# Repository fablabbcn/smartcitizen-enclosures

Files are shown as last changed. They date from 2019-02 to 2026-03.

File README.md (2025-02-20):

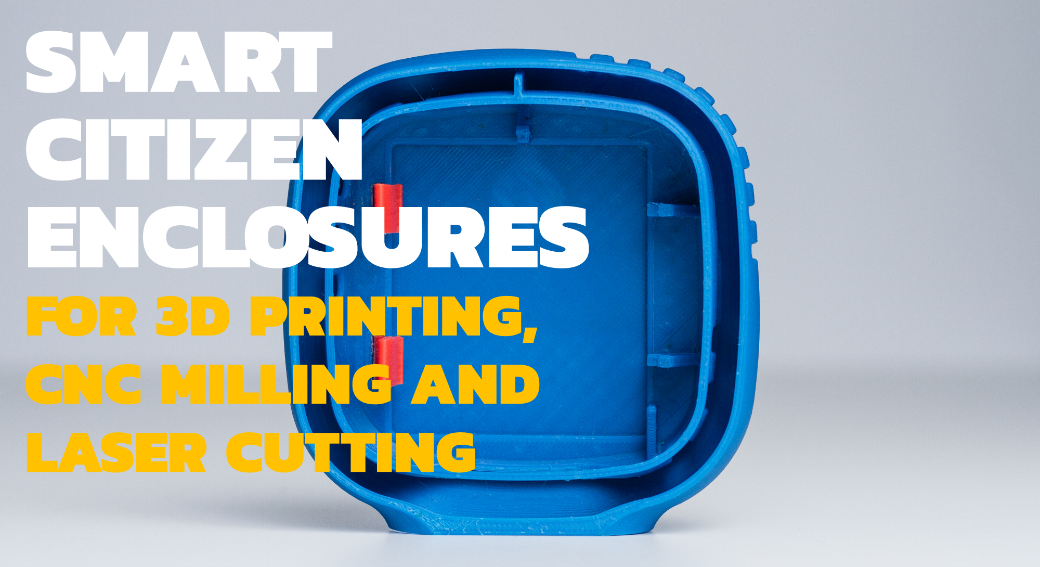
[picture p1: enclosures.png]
Smart Citizen Cases


Smart Citizen Enclosures
========================



This is a repository we host enclosures we are developing for the Smart Citizen Kit 1.5 and 2.X family. If you are looking for outdoor cases for the _SmartCitizen Kit or Stations_, make sure to visit the [variants table](/Air/) to find out what best suits your needs. If you are looking for _Water Kits or Stations_, check this [table](/Water/)

### Warning

Please, beware that this is always a _work in progress archive_. Sometimes documentation might be missing. Open an [issue](https://github.com/fablabbcn/smartcitizen-enclosures/issues) if you need!

### Contribute

* [Download](https://github.com/fablabbcn/smartcitizen-enclosures/archive/master.zip) and 3D print the files.
* Ask questions on [Issues](https://github.com/fablabbcn/smartcitizen-enclosures/issues).
* Share your changes using [Pull Requests](https://github.com/fablabbcn/smartcitizen-enclosures/pulls).
* Show and discuss your designs in the [forum](https:forum.smartcitizen.me).

### License

<br />This work is licensed under a <a rel="license" href="http://creativecommons.org/licenses/by-nc-sa/4.0/">Creative Commons Attribution-NonCommercial-ShareAlike 4.0 International License</a>.

### Credits

* Content under folder `SmartCitizen Case V1.5.1` has received funding from the European Union's Horizon 2020 research and innovation program under the grant agreement No. [688620](https://cordis.europa.eu/project/rcn/199877/factsheet/en)

* Content under folder the other folders has received funding from the European Union's Horizon 2020 research and innovation program under the grant agreement No. [689954](https://cordis.europa.eu/project/rcn/202639/factsheet/en)

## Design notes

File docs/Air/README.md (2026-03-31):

# Air Quality enclosures

These are examples of some outdoor cases for the different versions of the SCK with other sensors. You will find full 3D printed solutions, or some more complex solutions to be milled in a CNC on plastic.

!!! info "How to contribute?"
    You can download the files and make them. If you edit them or want to contribute, you can upload them to this repository with a [Pull Request!](https://github.com/fablabbcn/smartcitizen-enclosures/pull/new/master).

We give some recommendations for each enclosure's fabrication process in each design's folder. 

!!! warning "No enclosure is perfect"
    Keep in mind that no enclosure is perfect and that it will not compensate fully sun radiation and/or humidity extremes. All the enclosures in this folder have been tested, but keep in mind that outdoor conditions can be unpredictable.

## Variants

The table below will guide you through the selection process of your enclosure:

{{ insert_cards(card_type="unit", filter="page_type", value="version_index") }}

### Community contributed enclosures

|ID		|Sensors					|Exposure				|Extras		|Process		|Files 																														|
|:-:	|:-:						|:-:					|:-:		|:-:			|:-: 																															|
|	[Prius1954](https://github.com/Prius1954) |SCK2.1 + PMS50003			|-						|-			|3D Printing	|[Files](/Air/SCK2.1/SCK2.1_PMS5003/3D Printed SCK2.1 IaaC Style)												|
|	[Viadukaduk](https://lawaai.viadukaduk.be/)	|SCK2.1 + PMS50003			|OUTDOOR				|-			|3D Printing	|[Files](/Air/SCK2.1/SCK2.1_PMS5003/3D Printed Modular Viadukaduk/)													|
|		| SCK2.1 + PMS50003			|OUTDOOR				|-			|3D Printing	|[Files](/Air/SCK2.1/SCK2.1_PMS5003/3D Printed Prototype/)															|
| [serialc](https://www.printables.com/es/@serialc_251995) |SCK2.1 + PMS5003 + GPS 	|OUTDOOR - Bike mounted |- 			|3D Printing 	|[Link](https://www.printables.com/es/model/219574-smart-citizen-kit-21-case-supports-and-bicycle-mou)  						|
| [COKLIMAx](https://www.iigs.uni-stuttgart.de/forschung/coklimax/) |SCK2.1 + PMS5003 | OUTDOOR | | 3D Printing |[Files](/Air/SCK2.1/SCK2.1_PMS5003/SCK_3Dprint_Assembly_GER_EN_USTTG_IIGS_2023/) |

### Auxiliaries

|ID 	|Process					|Files 																													|Description												|
|:-:	|:-:						|:-:																													|:-:														|
|AUX001	|Sheet metal 				|[Files](/Air/SCK2.1/SCK2.1_PMS5003/CNC HDPE circle/drawing_metal_sheet.pdf)										| Inox flange with mounting points for Power Supply			|
|AUX002	|Dibond bending 			|[Files](/Air/SCK2.1/SCK2.1_PMS5003/3D Printed square/)	 											| Small umbrella cover 										|
|AUX003	|Dibond bending 			|[Files](/Air/shared/umbrella/)																| Medium umbrella cover										|
|AUX004	|Dibond bending 			|[Files](/Air/shared/umbrella/) 																| Large umbrella cover										|

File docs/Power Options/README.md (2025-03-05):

Power Options
========================

The Smart Citizen Kit can be powered with a normal 5V 2A USB charger via micro USB port. Outdoor deployments, or more complex setups (like the Smart Citizen Station), require a more rugged power supply. More documentation available [in the docs](https://docs.smartcitizen.me/hardware/addons/power-supply/). Here are some options:

## Smart Citizen Power Supply

A simple power supply to power the SCK with a 230AC input, with 5VDC 2A output.



The power supply can be one of two options:

- MeanWell-IRM-10-5 (datasheet in [References](References/IRM-10-SPEC.PDF) folder and [here](https://www.meanwell.com/Upload/PDF/IRM-10/IRM-10-SPEC.PDF))
- TracoPower-TMPS-10105 (datasheet in [References](References/) folder and [here](https://www.tracopower.com/products/tmps10.pdf))

It also comes with a 1.6A input fuse and two screw connectors. Check the datasheets for other available input convertions and limits.

The PCB has the footprint to fit inside a [Bopla Polymas PK 102-211](#enclosure) IP65 Enclosure with two built-in cable glands.

The hardware design files can be downloaded as a zip file [here](/Power Options/PowerSupply/power-supply-design-files.zip).

## Solar Panel

We recommend a Solar Panel from [Voltaic Systems](https://voltaicsystems.com/), either the [6W 6V option](https://voltaicsystems.com/6-watt-panel/) or the [5W 6V version](https://voltaicsystems.com/__socialshop/5-watt-panel-etfe/).

We use an MPTT Sunflower Solar power manager 5V [from DF Robot](https://wiki.dfrobot.com/Solar_Power_Manager_5V_SKU__DFR0559) for managing the solar input with an additional 2Ah battery. It is fitted inside the enclosure with a small laser cut (or 3D printed if not available) [flange](Solar/FLANGE3mm.stl). This is the [BOM](Solar/SCK_OUTDOOR_PV_BOM.csv) for this option.

## Enclosure

A [Bopla Polymas PK 102-211](https://www.bopla.de/en/enclosure-technology/euromas-polymas/enclosures-with-cable-glands/enclosure-with-2-moulded-on-pg-11/pk-102-211) enclosure is used for both options. The models can be found in the manufacturer's site in STP format. More [references](https://github.com/fablabbcn/smartcitizen-enclosures/tree/master/enclosures/Power%20Options/References) are available on our GitHub repository.

## Extras

Some extras are included in this folder for cases in which power distribution + USB data is needed, or a tiny board to host a reset button:

- [Power hub](Power%20hub/)
- [Reset button](Reset%20button)

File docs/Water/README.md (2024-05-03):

# Water enclosures

The enclosures in this folder are meant to be used with water probes. The design is normally made out of two main components:

- an [_electronics box_](Electronics/) which contains at least the _SC Data Board_ and some additional electronics for power and probe interface and
- a [_probe holder_](Probe Holders/), which literally, holds the sensor probes (i.e. a single pH sensor probe, or multple other probes of various kinds).

Both are connected via variable length cables (3m, 7.5m, 15m...).



There are various versions of these enclosures and probe holders, some of them more refined than others. Typically, we can classify them in two groups: [Smart Citizen Water Kit](Electronics/SmartCitizen%20Water%20Kit/) for one probe, and [Smart Citizen Water Station](Electronics/SmartCitizen%20Water%20Station/). Make sure to check each folder to see what you are getting, BOM and more components.

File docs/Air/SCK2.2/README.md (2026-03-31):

---
card: true
type: unit
name: SCK2.2 Enclosures
page_type:
  - version_index
field:
  - air
grade: intermediate
feature_img: /assets/images/2.2/SCKit_22.png
hide:
  - toc
---

# {{ name }}

These are enclosures for the SCK2.2 and the sensors it supports. Most enclosures in this section are the same as the ones in [SCK2.3](/Air/SCK2.3).

## Variants

{{ insert_cards(card_type = "unit", filter = "page_type", value = ['enclosure'])}}

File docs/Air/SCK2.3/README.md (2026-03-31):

---
card: true
type: unit
name: SCK2.3 Enclosures
page_type:
  - version_index
field:
  - air
grade: intermediate
feature_img: /assets/images/2.3/SCKit_23.png
hide:
  - toc
---

# {{ name }}

These enclosures are compatible with the SCK2.3 and the different sensors it supports.

## Variants

{{ insert_cards(card_type = "unit", filter = "page_type", value = ['enclosure'])}}

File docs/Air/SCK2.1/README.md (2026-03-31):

---
card: true
type: unit
name: SCK2.1 Enclosures
page_type:
  - version_index
field:
  - air
grade: intermediate
feature_img: /assets/images/2.1/SCKit_21.png
hide:
  - toc
---

# {{ name }}



## Variants

{{ insert_cards(card_type = "unit", filter = "page_type", value = ['enclosure'])}}

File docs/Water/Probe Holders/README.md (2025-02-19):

# Probe holders

The probe holders in this folder are meant to do just that: hold in place water/soil sensor probes of various kinds. We typically use [Atlas Scientific](https://atlas-scientific.com/) probes, but other such as [DF-robot](https://www.dfrobot.com/search-water%20sensor.html) have similar shapes and could be adapted.

We normally use ABS or PVC plumbing pipes with some custom _3D printed_ parts in ASA or ABS. Then, we use some [316 stainless steel](https://en.wikipedia.org/wiki/Marine_grade_stainless) nuts and screws to keep everything together. Check each folder in case you are looking for a [single](single/) or [multiple](multiple/) probes.

<!-- ![](/assets/images/water/water-station-pipe vid.gif) -->

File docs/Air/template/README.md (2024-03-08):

## Printing settings

### Clip

### Base

### Cover

### Clip

### Latch/Hinge

## Materials

You will need:

### Components

**Important** 

### Assembly

You will need:

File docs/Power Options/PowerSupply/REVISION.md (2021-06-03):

V1
Added options for traco and meanwell. Input fuse and output led.

V1.1
TODO - Add VCR for inrush current protection

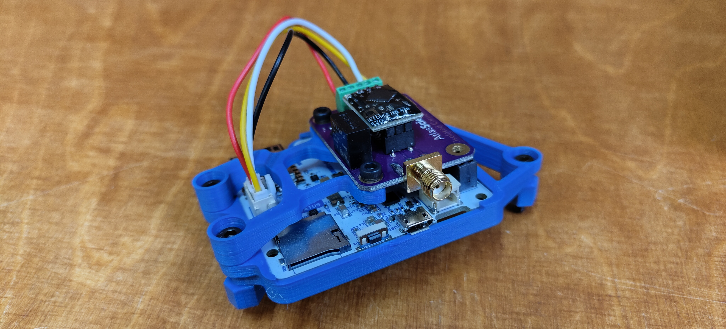
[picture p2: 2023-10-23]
docs/Water/Electronics/SmartCitizen Water Kit/IP Box One Carrier/SCK_T2_01.jpg

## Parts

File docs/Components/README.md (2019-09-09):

Individual models are shown here for each of the hardware components. Some drawings are also included in some boards.

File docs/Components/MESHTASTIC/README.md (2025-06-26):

These files are based on the models provided by Seeed Studio in [printables.com](https://www.printables.com/)
- [Seeed Studio XIAO ESP32S3 Plus](https://www.printables.com/model/1326291-3d-model-for-seeed-studio-xiao-esp32s3-plus)
- [Expansion Board for Seeed Studio XIAO](https://www.printables.com/model/1336695-3d-model-for-the-expansion-board-for-seeed-studio)

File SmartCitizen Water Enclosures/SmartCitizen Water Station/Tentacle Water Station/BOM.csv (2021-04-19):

part_name | part_description | quantity | Supplier | SKU | Manufacturer | MPN
Enclosure
Fibox PCM 150/100 T enclosure | Fibox transparent box | 1 | RS Componentes | 498-5129 | Fibox | PCM 150/100 T enclosure
ICOTEK_QVT_20 | SPLIT CABLE GLAND QVT 20 wo grommet | 2 | Kolbi |  | ICOTEK | QVT_20
ICOTEK_QVT_16 | SPLIT CABLE GLAND QVT 16 wo grommet | 1 | Kolbi |  | ICOTEK | QVT_16
ICOTEK GROMMET FULL | ICOTEK GROMMET WO HOLE | 1 | Kolbi |  | ICOTEK
ICOTEK GROMMET ONE | ICOTEK GROMMET w/ one hole | 1 | Kolbi |  | ICOTEK
ICOTEK GROMMET FOUR | ICOTEK GROMMET w/ four holes | 1 | Kolbi |  | ICOTEK
GPS
Adaptor U.FL SMA Hembra | Adaptor U.FL SMA Hembra | 1 | Mouser | 474-WRL-09145 | Sparkfun | WRL-09145
Magnetic Mount Antenna GPS/GLONASS/Galileo/BeiDou | Antennas Magma X AA.170 GPS/GLONASS/Galileo/BeiDou Magnetic Mount Antenna | 1 | Mouser | 960-AA.170.301111 | Taoglas | AA.170.301111
GPS_14414 | SparkFun GPS Breakout - XA1110 (Qwiic) | 1 | Digikey | 1568-1742-ND | Sparkfun | GPS-14414
QWIIC_GROVE_ADAPTOR | Accesorios SparkFun Qwiic Cable - Grove Adapter (100mm) | 1 | Mouser | 474-PRT-15109 | Sparkfun | PRT-15109
Cable
USB_BULGIN_CONN_OUT | external bulgin usb connector | 1 | Mouser | 167-PXP4040/B/2M00 | Bulgin | PXP4040/B/2M00
USB CABLE | USB 90deg CABLE | 1 | RS Componentes | 186-2824 | Startech | UUSBHAUB1RA
USB_BULGIN_CONN_IN | internal bulgin usb connector | 1 | Mouser | 167-PXP4043/B | Bulgin | PXP4043/B
USB_BULGIN_SEALING_CAP | Conector circular estándar Sealing Cap For 4000 Power and Data Conns | 1 | Mouser | 157-PXP4083 | Bulgin | PXP4083
Smart Citizen Boards
GROVE HUB 4 CH | SEEED Studio Grove Hub | 1 | Mouser | 713-103020006 | SEEED | 103020006
DATA 2.1.1 | Data Board 2.1.1 | 1 | SC | DATA_BOARD | SC | DATA_BOARD
SC_POWER_HUB | Smart Citizen Power Hub | 1 | SC | POWER_HUB | SC | POWER_HUB
Atlas scientific sensors
Sensors
TENTACLE T3 | Tentacle T3 Carrier Board | 2 | Atlas Scientific | T3 | White Labs | T3
PT-1000 Temperature Probe | Atlas Scientific PT-1000 Temperature Probe | 1 | Atlas Scientific | PT-1000 | Atlas Scientific | PT-1000
pH Probe | Atlas Scientific Lab Grade pH Probe | 1 | Atlas Scientific | ENV-40-pH | Atlas Scientific | ENV-40-pH
Conductivity Probe K10 | Atlas Scientific Conductivity Probe K 10 | 1 | Atlas Scientific | ENV-40-EC-K10 | Atlas Scientific | ENV-40-EC-K10
Dissolved Oxygen Probe | Atlas Scientific Dissolved Oxygen Probe | 1 | Atlas Scientific | ENV-40-DOX | Atlas Scientific | ENV-40-DOX
Driver RTD Temperature Circuit | Atlas Scientific RTD Temperature Circuit | 1 | Atlas Scientific | EZO-RTD | Atlas Scientific | EZO-RTD
Driver pH Sensor | Atlas Scientific Driver pH Circuit | 1 | Atlas Scientific | EZO-pH | Atlas Scientific | EZO-pH
Driver Conductivity Circuit | Atlas Scientific Driver Conductivity Circuit | 1 | Atlas Scientific | EZO-EC | Atlas Scientific | EZO-EC
Driver Dissolved Oxygen Circuit | Atlas Scientific Driver Dissolved Oxygen Circuit | 1 | Atlas Scientific | EZO-DO | Atlas Scientific | EZO-DO

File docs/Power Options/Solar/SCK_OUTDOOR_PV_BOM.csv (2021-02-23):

part_name | part_description | Supplier_0 | SKU_0 | Manufacturer_0 | MPN_0
IP_BOX_BOPLA | Bopla Euromas Polymas Junction Box, IP65, 98mm x 64mm x 34mm | RS Components | 266-3120 | Bopla | 38102200
BATT_2000MAH | 2000mAh LiPo Battery | SEEED | BATT2000 | SEEED
USB_CABLE_TRIMMED | Cable USB USB A, USB Micro B, 0.5m, Negro, Micro USB B macho a Cable desnudo | RS Components | 173-3530 | RS PRO
DF_ROBOT_MPTT | Herramientas de desarrollo IC de gestión de energía Sunflower: Solar Power Manager 5V | Mouser | DFR0559 | DF Robot | DFR0559
SOLAR_PANEL_3.5X1.1MM_EXT_CABLE | 3.5x1.1mm Extension Cable - 10 Foot | Voltaic Systems | 3511-EXT-10FT | Voltaic Systems | 3511-EXT-10FT
SOLAR_PANEL_BRACKET | Solar Panel Bracket - Medium | Voltaic Systems | MOUNT-BRACKET-M | Voltaic Systems | MOUNT-BRACKET-M
SOLAR_PANNEL_6W | 6 Watt 6 Volt Solar Panel | Voltaic Systems | 6.0W-PANEL | Voltaic Systems | 6.0W-PANEL
CONN RSPT 6POS IDC 28-30AWG GOLD | CONN RCPT 6POS IDC 28-30AWG GOLD

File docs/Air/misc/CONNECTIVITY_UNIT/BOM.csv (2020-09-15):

Qty | Item | Supplier | Stock No. | Link
1 | RS PRO Mounting Kit | RS ONLINE | 746-7387 | https://uk.rs-online.com/web/p/products/7467387/
1 | Ventilation Valve | RS ONLINE | 174-9496 | https://uk.rs-online.com/web/p/enclosure-accessories/1749496/?sra=pstk
1 | RS PRO PG13.5 | RS ONLINE | 822-9672 | https://uk.rs-online.com/web/p/cable-glands/8229672/?sra=pstk
1 | 3m power AC cable | RS ONLINE | 490-245 | https://uk.rs-online.com/web/p/power-cable-assemblies/0490245/?sra=pstk
1 | German Schuko | RS ONLINE | 824-5560 | https://uk.rs-online.com/web/p/mains-plugs-sockets/8245560/?searchHistory=%7B%22enabled%22%3Atrue%7D
2 | LPRS Male SMA to Female SMA RG174 Coaxial Cable, 50 Ω | RS ONLINE | 783-9644 | https://uk.rs-online.com/web/p/coaxial-cable/7839644/?sra=pstk
2 | Antena 2.4Ghz SMA Outdoor | RS ONLINE | 793-4379 | https://uk.rs-online.com/web/p/wifi-antennas/7934379/?sra=pstk
1 | RS PRO ABS Wall Box, IP65 | RS ONLINE | 769-6125 | https://uk.rs-online.com/web/p/wall-boxes/7696125/?sra=pstk

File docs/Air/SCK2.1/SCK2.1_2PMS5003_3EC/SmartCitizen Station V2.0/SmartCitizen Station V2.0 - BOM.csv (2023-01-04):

Qty. | Item | Major Provider | ~ PPU (€) | ~ PPS (€)
1 | 500 Density HDPE body (6 blue + 2 white layers) | Manifiesto Design | 320 | 320
1 | 3mm thick PET-G top cover | Manifiesto Design | 0 | 0
12 | M4 Brass barbed expansion Inserts | Manifiesto Design | 0 | 0
3 | M3 Brass barbed expansion Inserts | Manifiesto Design | 0 | 0
8 | M2.5 Brass barbed expansion Inserts | Manifiesto Design | 0 | 0
6 | 70cm long EPDM 5mm O-ring cord piece | Manifiesto Design
3 | DIN 912 M4 x 45 INOX screw | Ferretería Bonet | 0.151 | 0.453
3 | DIN 912 M4 x 30 INOX screw | Ferretería Bonet | 0.192 | 0.576
3 | DIN 912 M4 x 20 INOX screw | Ferretería Bonet | 0.034 | 0.102
3 | ISO 7380 M4 x 20 INOX screw | Ferretería Bonet | 0.12 | 0.36
4 | T-Slot Nut EU30-M6 | Amazon | 0.46 | 1.84
4 | DIN933 M6 x 10 INOX Screw | Ferretería Bonet | 0.154 | 0.616
4 | DIN933 M6 x 15 INOX Screw | Ferretería Bonet | 0.146 | 0.584
4 | DIN933 M6 x 20 INOX Screw | Ferretería Bonet | 0.161 | 0.644
4 | DIN933 M6 x 25 INOX Screw | Ferretería Bonet | 0.185 | 0.74
4 | DIN9021 M6 INOX Washer | Ferretería Bonet | 0.059 | 0.236
2 | 30 cm piece of Galvanized Steel Perforated Tape 17 mm x 0,8 mm x 10 m | Amazon | 0.53 | 1.06
1 | 16x1.5mm Plastic Cable Glands | Sesaelec | 0.47 | 0.47
1 | QVT 20 - Cable Grommet M20 x 1.5, Icotek | Distrelec | 7.66 | 7.66
1 | QT4 | Distrelec | 1.3 | 1.3
 | QTB (Blind) | Distrelec
1 | SCK PM board | SEEED Studio | 22.99 | 22.99
2 | Plantower PMS5003 | Aliexpress | 12.17 | 24.34
2 | SCK PM Board to Plantower PMS5003 cable | Aliexpress | 0 | 0
1 | SCK Gas Sensor Board | SEEED Studio | 129 | 129
1 | Alphasense CO-B4 | Alphasese LTD | 53 | 53
1 | Alphasense NO2-B43F | Alphasese LTD | 53 | 53
1 | Alphasense OX-B431 | Alphasese LTD | 58 | 58
1 | Seeed Studio Universal 4 Pin Buckled 5 cm cable | SEEED Studio | 0.324 | 0.324
1 | Seeed Studio Universal 4 Pin Buckled 20 cm cable | SEEED Studio | 0.494 | 0.494
1 | SCK Data Board | SEEED Studio | 70 | 70
1 | SCK Urban Sensor Board | SEEED Studio | 0 | 0
1 | SD card 512kB | Amazon | 0 | 0
1 | One Wire Sensor | SEEED Studio | 8.68 | 8.68
1 | 15 cm long Aluminium Tube int. Ø8 x ext. Ø10 | Servei Estacio |  | 0
3 | Nylon Cheese Head Machine Screws M3 x 6 | Farnell | 0.065 | 0.195
5 | Nylon Cheese Head Machine Screws M2.5 x 6 | Farnell | 0.076 | 0.38
3 | Nylon Cheese Head Machine Screws M2.5 x 12 | Farnell | 0.076 | 0.228
1 | 2m USB-A to angled microUSB-B cable | Tiendacables | 5.49 | 5.49
1 | 5V 1500 mA USB Power adapter | Amazon | 5.99 | 5.99
1 | 3D Printed Frame | Aitor |  | 0
3 | 3D Printed spacers | Aitor |  | 0
1 | O-ring NBR 52x2 | Cauchos Barna | 0.25 | 0.25
2 | 8-pin Stackable Female Header | SparkFun | 0.6 | 1.2
1 | 8000mAh LiPo Battery | Aliexpress | 24.41 | 24.41
1 | 6000mAh LiPo Battery | Bricogeek
8 | 10gr Silica Gel Bags | Cablematic | 0.15 | 1.2
1 | Loctite | Amazon | 7.03 | 7.03
1 | Nail Polish | Chinese Shop | 2 | 2
1 | Jintsu Glue | Ferretería Bonet | 4.96 | 4.96
1 | 2.5 mm Allen key | Ferretería Bonet | 0.312 | 0.312
1 | 3 mm Allen Key | Ferretería Bonet | 0.36 | 0.36
1 | 10-11 Double Open Ended Spanner | Amazon | 3.4 | 3.4
1 | Buck-Boot for PV panel!?!?!? | Adafruit |  | 0
1 | 220 AC/DC power adapter!?!?! | Aliexpress | 2.61 | 2.61
1 | 2 Pin Screw Terminal | Amazon
1 | 90º angle usb | Aliexpress |  | 0
1 | iScape Triangular Sticker | Camaloon |  | 0
1 | "Funded by" Sticker | Camaloon |  | 0
1 | Serial Number Sticker | Camaloon |  | 0

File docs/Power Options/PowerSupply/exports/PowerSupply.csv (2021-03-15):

Id | Designator | Package | Quantity | Designation | Supplier and ref
1 | REF**, | PAD | 2 | PAD
2 | MW-IRM10 | MeanWell-IRM-10-5 | 1 | MeanWell-IRM-10
3 | FUSE:1.6A | Fuse_Littelfuse_646Series | 1 | Fuse
4 | J1 | TerminalBlock_Phoenix_PT-2,5-2-5.0-H_1x02_P5.00mm_Horizontal | 1 | Screw_Terminal_01x02-AC_INPUT
5 | J2 | TerminalBlock_Phoenix_MKDS-1,5-2_1x02_P5.00mm_Horizontal | 1 | Screw_Terminal_01x02-DC_OUTPUT
6 | TMPS-10105 | Traco-TMPS-10-105 | 1 | TracoPower-TMPS-10105
7 | D1 | LED_D3.0mm | 1 | LED_RED
8 | R1 | R_Axial_DIN0207_L6.3mm_D2.5mm_P7.62mm_Horizontal | 1 | 1.8kOhm
9 | G*** | Logo_5000 | 1 | LOGO
10 | G*** | Name | 1 | LOGO

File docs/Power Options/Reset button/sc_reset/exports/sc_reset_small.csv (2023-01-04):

Comment | Designator | Footprint | JLCPCB Part #
MountingHole | H1,H2 | MountingHole:MountingHole_3.2mm_M3
Conn_02x05_Odd_Even | J1 | Connector_PinHeader_1.27mm:PinHeader_2x05_P1.27mm_Vertical_SMD
Conn_02x03_Odd_Even | J2 | Connector_PinHeader_1.27mm:PinHeader_2x03_P1.27mm_Vertical_SMD | C178291
SW_SPST | SW1 | Button_Switch_SMD:SW_SPST_TL3342 | C318888
fablab | U1 | logos:fablab
sc | U2 | logos:smartcitizen

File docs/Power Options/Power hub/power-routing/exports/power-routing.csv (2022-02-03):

Comment | Designator | Footprint | LCSC
MountingHole | H1,H2,H3,H4 | MountingHole:MountingHole_3.2mm_M3
Input_Bulgin | J1 | Connector_PinHeader_2.54mm:PinHeader_1x05_P2.54mm_Vertical
Screw_Terminal_01x02 | J2,J3,J4 | TerminalBlock_Phoenix:TerminalBlock_Phoenix_PT-1,5-2-3.5-H_1x02_P3.50mm_Horizontal
USB_A | J6 | Connector_USB:USB_A_Amphenol_87520-1110BLF
RED | M1 | LED_SMD:LED_1206_3216Metric_Pad1.42x1.75mm_HandSolder | C93133
1000Ω | R1 | fab-R1206FAB | C4410
fablab | U1 | logos:fablab
smartcitizen | U2 | logos:smartcitizen

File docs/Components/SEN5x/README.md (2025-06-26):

These files are based on the models provided by Sensiron in [sensirion.com](https://sensirion.com/products/catalog/SEN50)

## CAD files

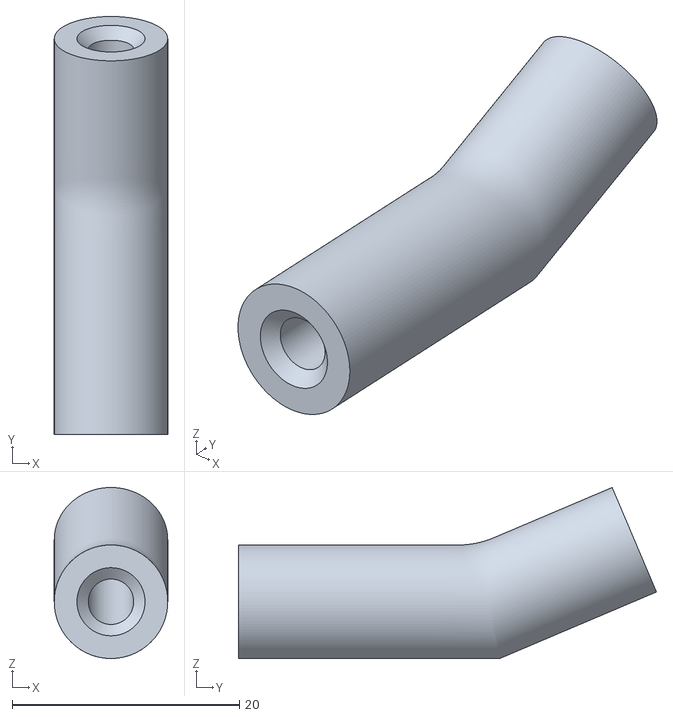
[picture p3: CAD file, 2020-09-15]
docs/Air/misc/CONNECTIVITY_UNIT/tube.stl
10.0 x 36.8 x 15.1

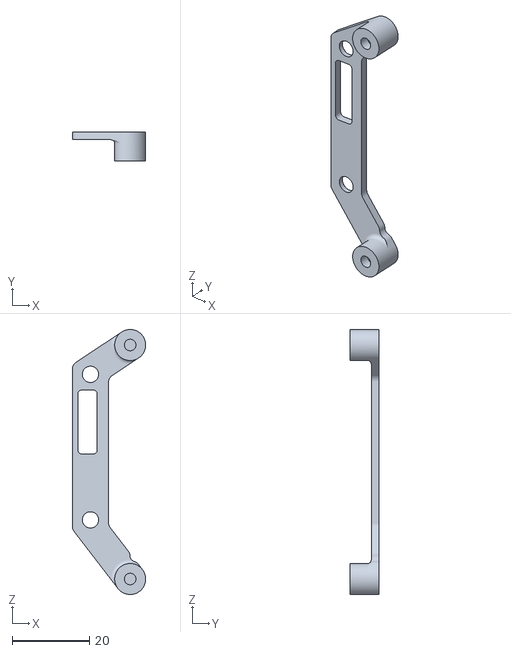
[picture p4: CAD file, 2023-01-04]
docs/Air/misc/SCK2.1_ANALOG_BOX/components/asb.stl
18.9 x 7.50 x 68.4

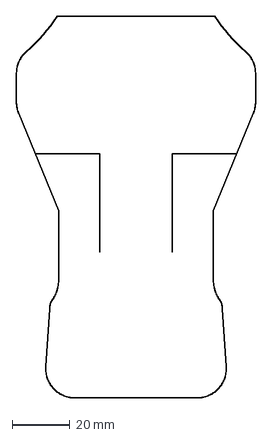
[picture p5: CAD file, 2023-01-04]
docs/Air/misc/SCK2.1_BIKE_SADDLEBAG/components/folding_vinyl.dxf
82.6 x 131.8 mm

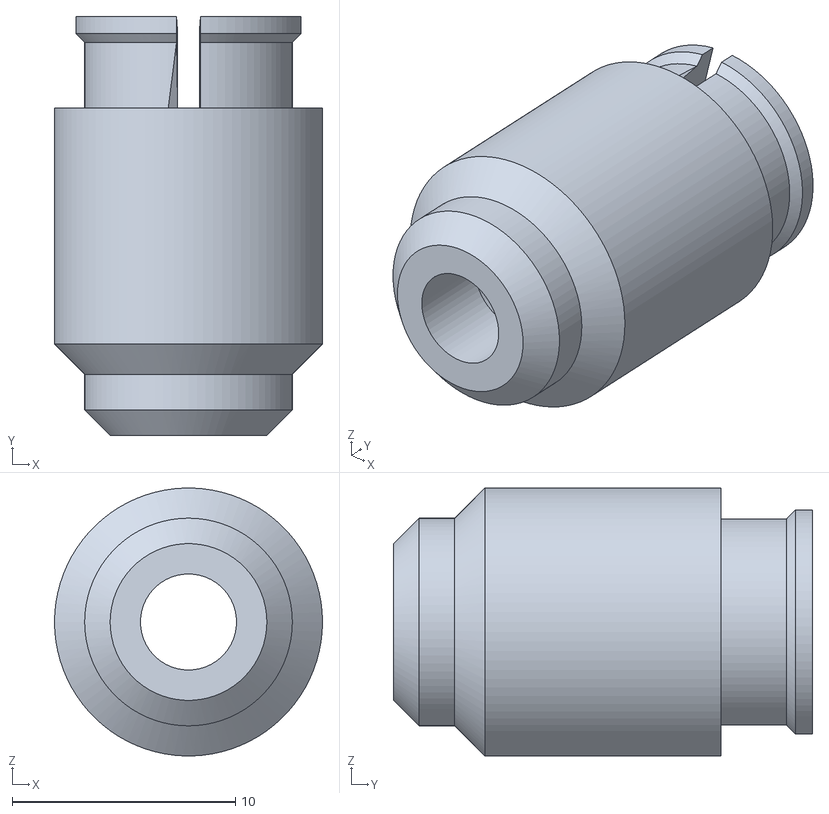
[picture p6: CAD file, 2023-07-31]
docs/Air/SCK2.1/SCK2.1_2PMS5003_4EC/4-electrochemical-alphasense-2pm/components/spacer-pm-board.stl
12.0 x 18.8 x 12.0

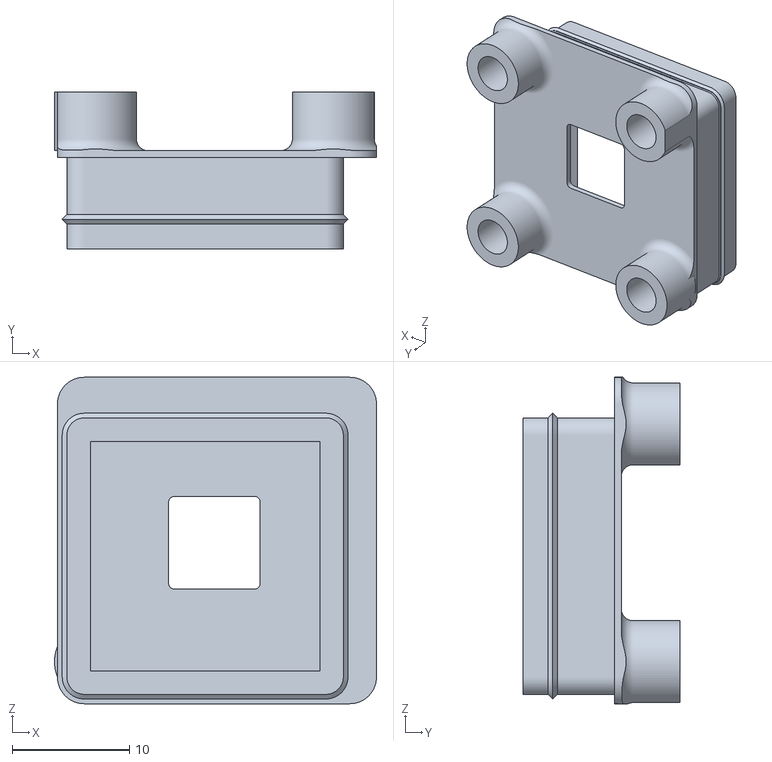
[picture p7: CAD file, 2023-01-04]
docs/Air/SCK2.1/SCK2.1_2PMS5003_6EC/6-electrochemical-spec-2pm/components/3DPRINTING/scd41-support.stl
27.5 x 13.4 x 27.9

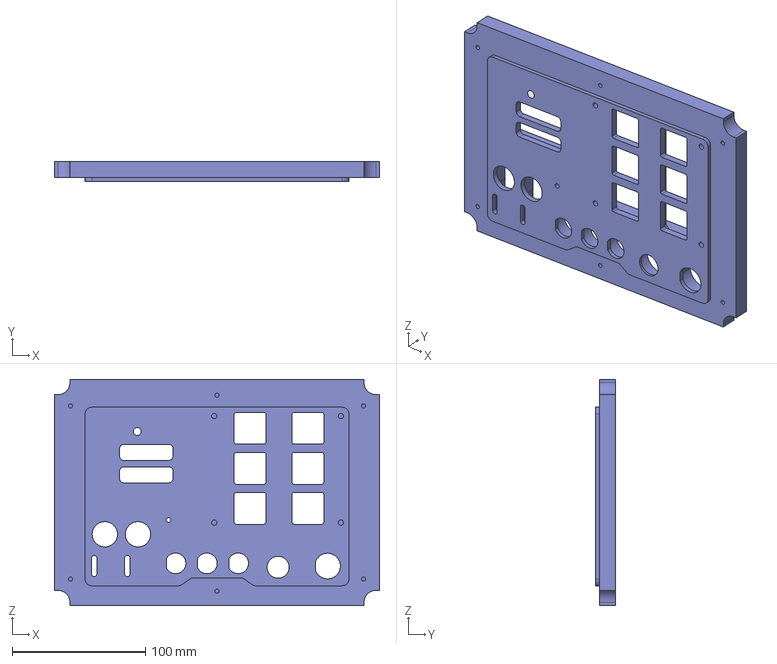
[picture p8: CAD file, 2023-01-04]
docs/Air/SCK2.1/SCK2.1_2PMS5003_6EC/6-electrochemical-spec-2pm/components/CNC/HDPE-0728.step
244.0 x 15.0 x 170.0 mm

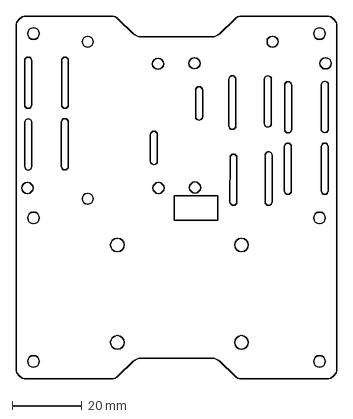
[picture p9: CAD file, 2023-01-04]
docs/Air/SCK2.1/SCK2.1_2PMS5003_6EC/6-electrochemical-spec-2pm/components/LASERCUT/acrylic-asb.dxf
92.0 x 104.0 mm

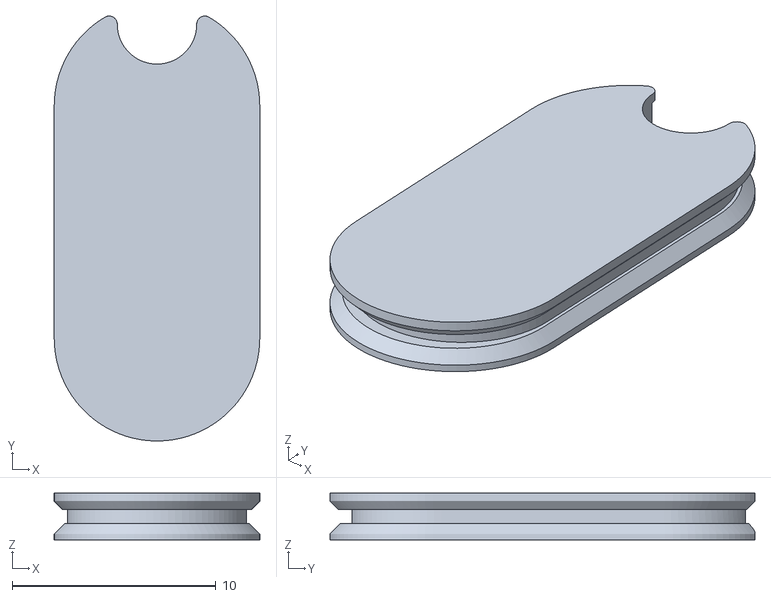
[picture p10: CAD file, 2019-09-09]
docs/Air/SCK2.1/SCK2.1_PMS5003/3D Printed + HDPE/components/GLAND.stl
10.1 x 20.9 x 2.30

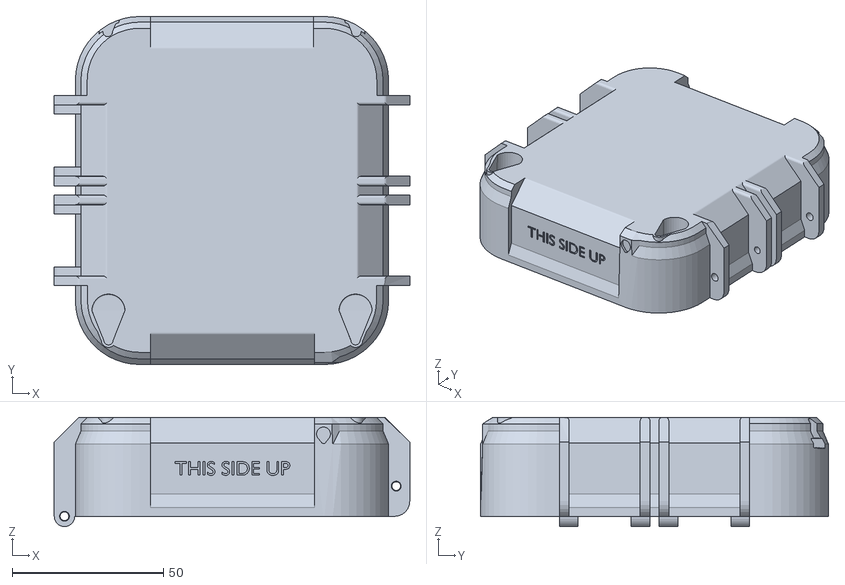
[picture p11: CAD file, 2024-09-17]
docs/Air/SCK2.1/SCK2.1_PMS5003/3D Printed frog box/components/cover_outdoor.stl
117.7 x 115.2 x 36.1

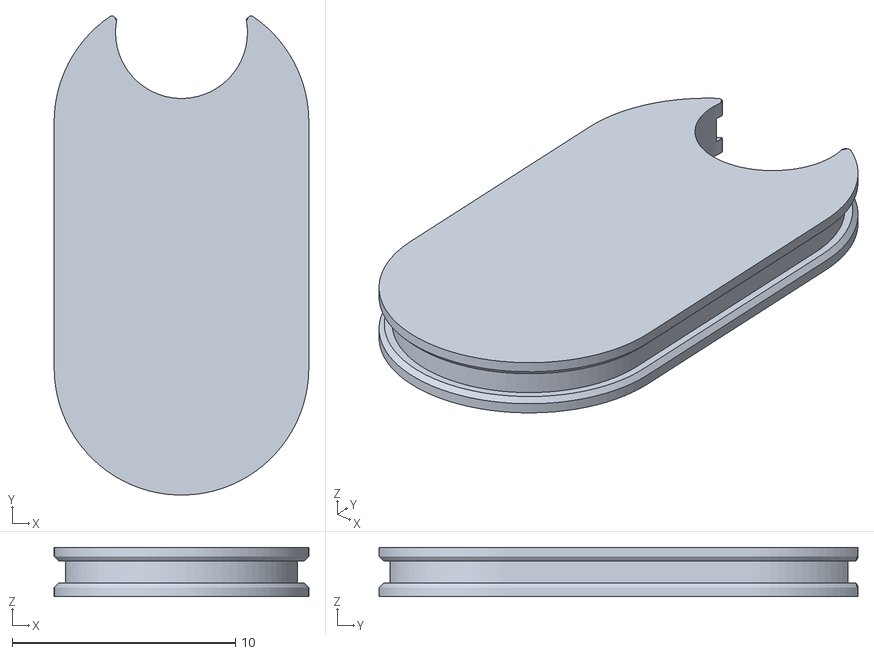
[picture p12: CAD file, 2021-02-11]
docs/Air/SCK2.1/SCK2.1_PMS5003/3D Printed Modular Viadukaduk/components/cable gland.stl
11.4 x 21.4 x 2.20

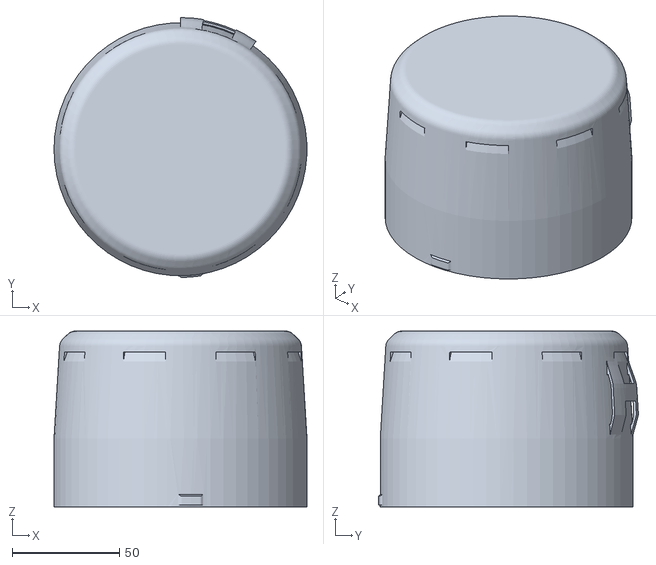
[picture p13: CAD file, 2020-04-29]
docs/Air/SCK2.1/SCK2.1_PMS5003/3D Printed Prototype/components/COVER25.STL
118.0 x 121.2 x 82.0

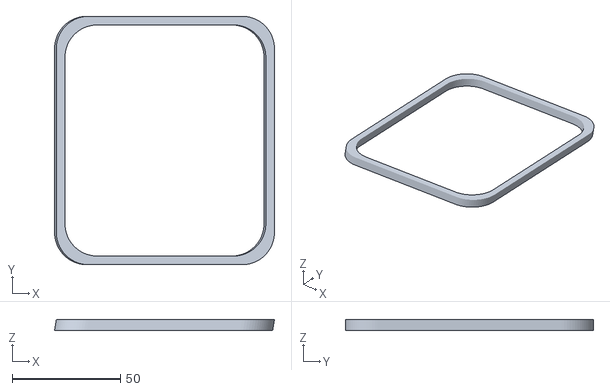
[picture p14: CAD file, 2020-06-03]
docs/Air/SCK2.1/SCK2.1_PMS5003/3D Printed SCK2.1 IaaC Style/Traba.stl
101.8 x 115.0 x 5.00

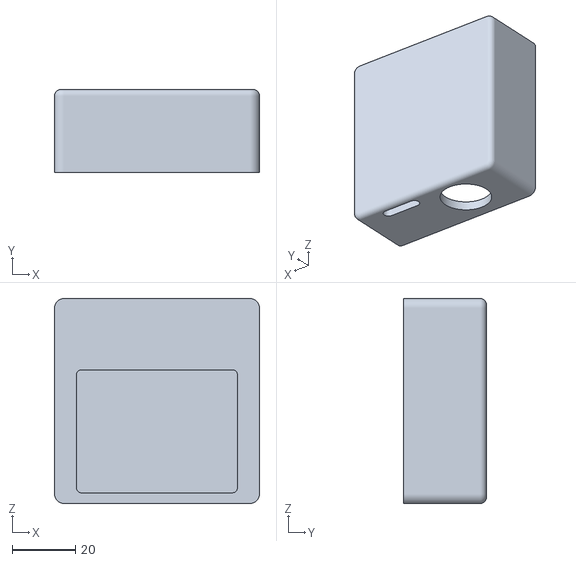
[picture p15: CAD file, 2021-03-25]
docs/Air/SCK2.1/SCK2.1_PMS5003/3D Printed Slim/cover.stl
65.0 x 26.3 x 65.0

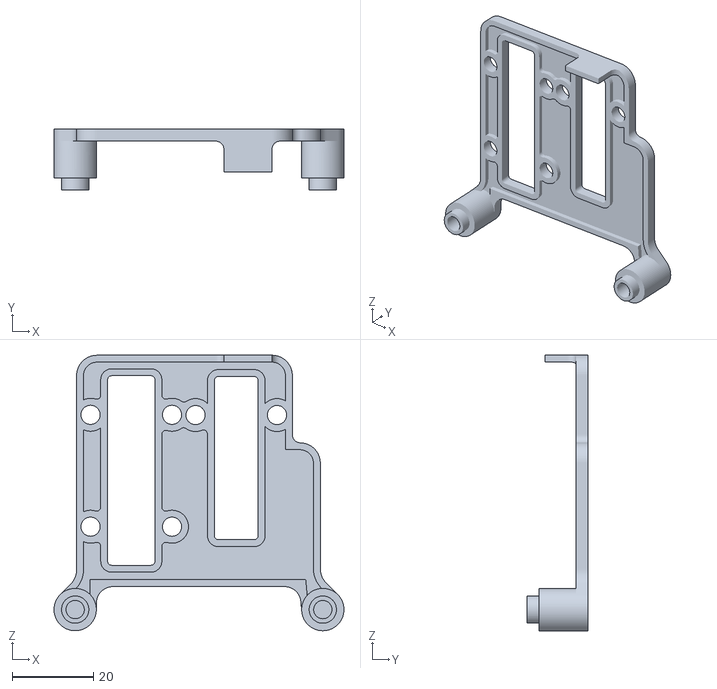
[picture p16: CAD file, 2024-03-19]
docs/Air/SCK2.1/SCK2.1_PMS5003/3D Printed square/components/holder-extras_new.stl
71.2 x 15.0 x 67.6

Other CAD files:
docs/Air/SCK2.1/SCK2.1_PMS5003/3D Printed square/UMBRELLA/cover.dxf
docs/Air/SCK2.1/SCK2.1_PMS5003/CNC HDPE circle/components/CAP_MIRROR.stl
docs/Air/SCK2.1/SCK2.1_PMS5003/CNC HDPE square/components/base.stl
SmartCitizen Air Enclosures/SCK2.1/SCK2.1 with PM Sensor/SCK2.1_PMS5003/3D Printed frog box v1/components/base_05.stl
SmartCitizen Air Enclosures/SCK2.1/SCK2.1 with PM Sensor/SCK2.1_PMS5003/3D Printed frog box v1/components/clamp_01.stl
SmartCitizen Air Enclosures/SCK2.1/SCK2.1 with PM Sensor/SCK2.1_PMS5003/3D Printed frog box v1/components/cover_04.stl
SmartCitizen Air Enclosures/SCK2.2/SCK2.2 with PM Sensor/SCK2.2_SEN5X/3D printed frog box INDOOR/components/latch_hinge.stl
SmartCitizen Air Enclosures/SCK2.2/SCK2.2 with PM Sensor/SCK2.2_SEN5X/3D printed frog box/components/SCKit_base.stl
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

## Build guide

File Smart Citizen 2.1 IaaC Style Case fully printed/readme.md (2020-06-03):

## Smart Citizen 2.1 IaaC Style Case fully printed

Here goes my interpretation (v1) of the enclosure, hacking the original one (thanks, Oscar, for the files!). 
Thought I’d give it some IaaC feeling :slightly_smiling_face:
Photos attached.
Still might need some improvement.
By the way, for keeping the housing relatively small, I have used a USB cable with an angled micro USB plug.

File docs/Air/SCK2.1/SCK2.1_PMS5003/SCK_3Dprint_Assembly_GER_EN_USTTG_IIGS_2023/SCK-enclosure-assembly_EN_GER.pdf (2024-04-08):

### Assembly of SCK-unit with CoKLIMAx 3D print enclosure

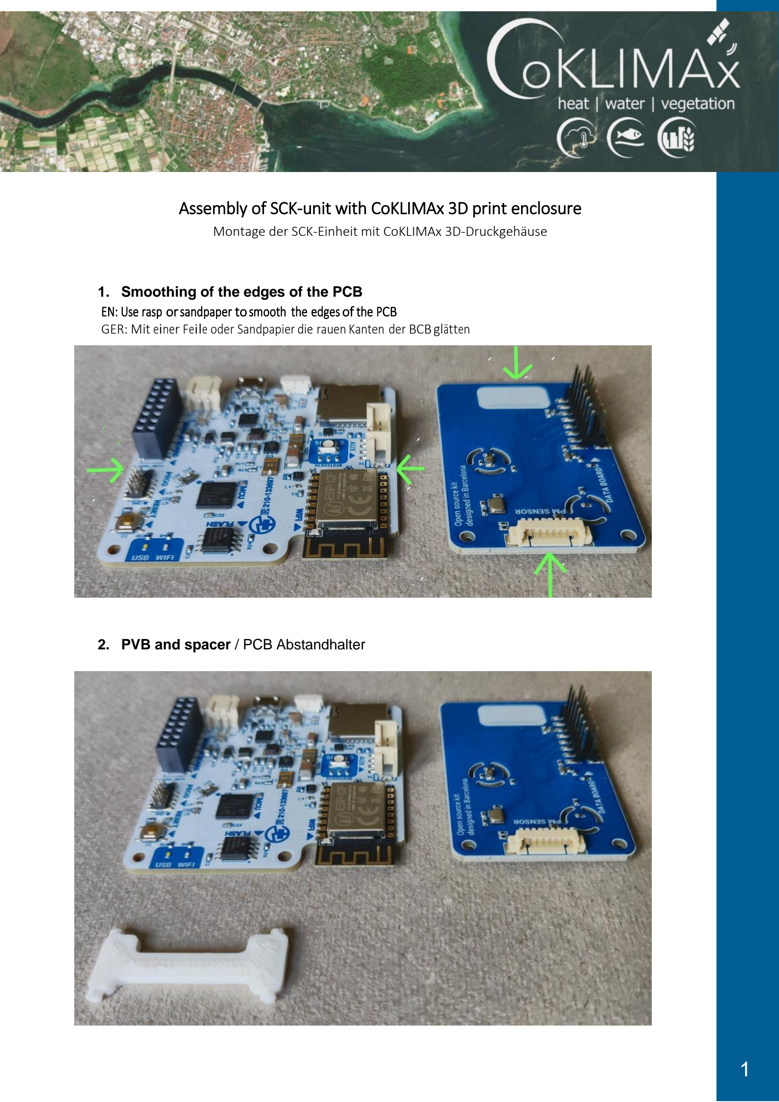
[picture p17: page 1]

Montage der SCK-Einheit mit CoKLIMAx 3D-Druckgehäuse

### 1. Smoothing of the edges of the PCB

EN: Use rasp or sandpaper to smooth the edges of the PCB
GER: Mit einer Feile oder Sandpapier die rauen Kanten der BCBglätten

### 2. PVB and spacer / PCB Abstandhalter

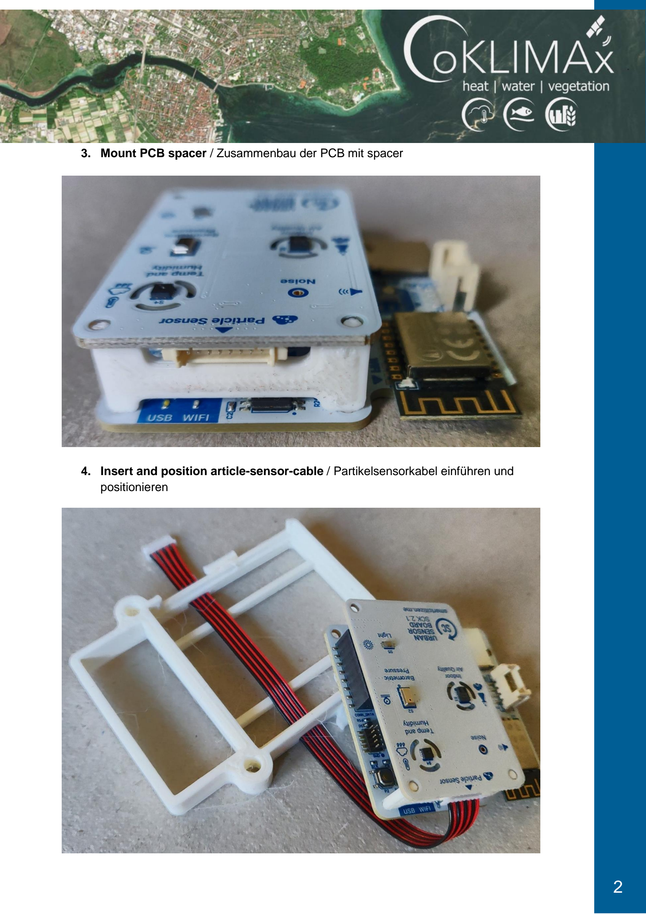
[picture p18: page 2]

### 3. Mount PCB spacer / Zusammenbau der PCB mit spacer

### 4. Insert and position article-sensor-cable / Partikelsensorkabel einführen und

positionieren

### 5. Insert the PCB into the device frame / Einsetzen der PCB in den Träger

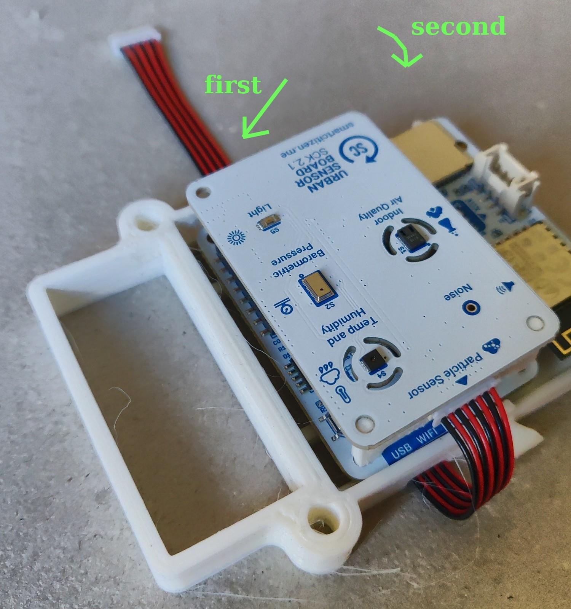
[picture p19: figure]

First, insert the PCB into the slot at the side of the particle-sensot.
Second, click the other end of the PCB into the frame.

Zuerst die PCB in den Schlitzen auf der Sseite des Partikelsensors einsetzen. Dann das andere Ende er der Platine in den Rahmen einklipsen.

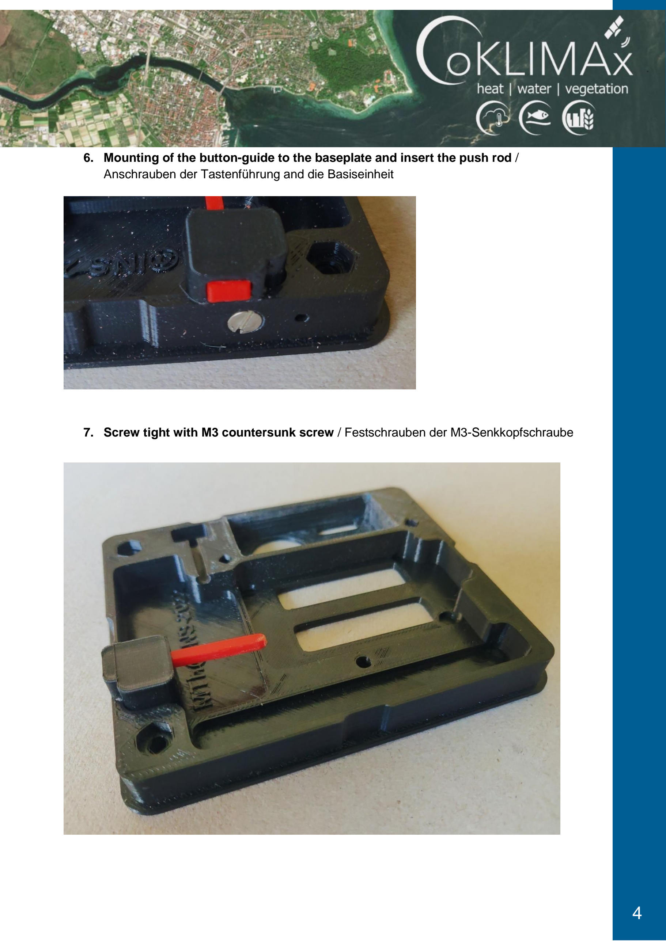
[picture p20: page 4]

### 6. Mounting of the button-guide to the baseplate and insert the push rod /

Anschrauben der Tastenführung and die Basiseinheit

### 7. Screw tight with M3 countersunk screw / Festschrauben der M3-Senkkopfschraube

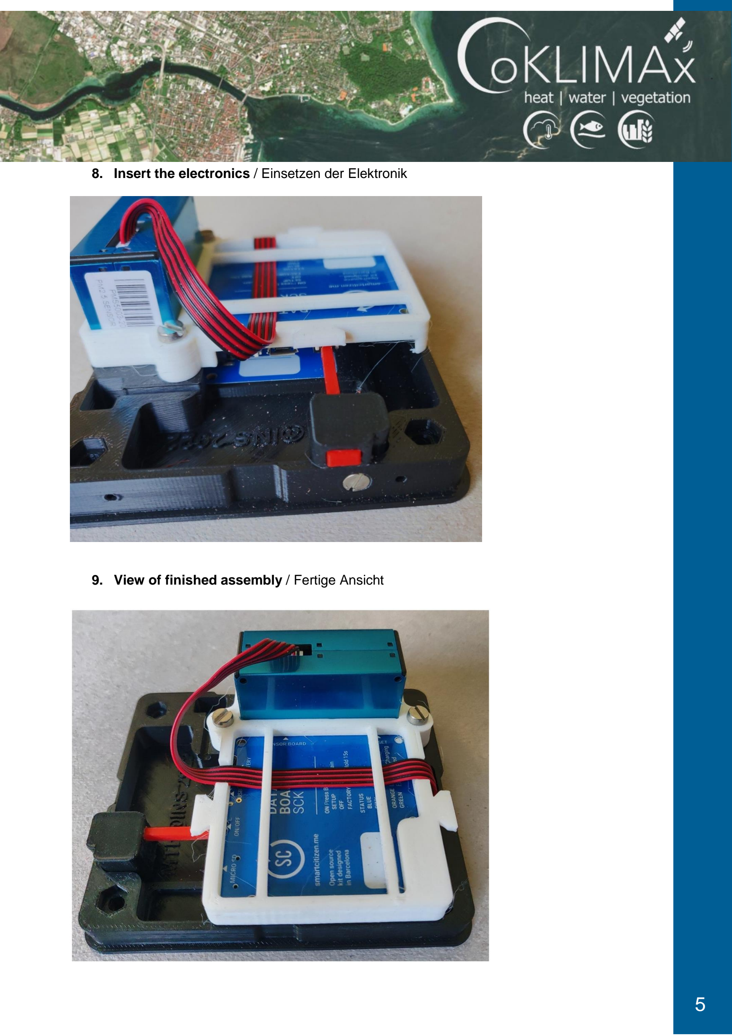
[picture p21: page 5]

### 8. Insert the electronics / Einsetzen der Elektronik

### 9. View of finished assembly / Fertige Ansicht

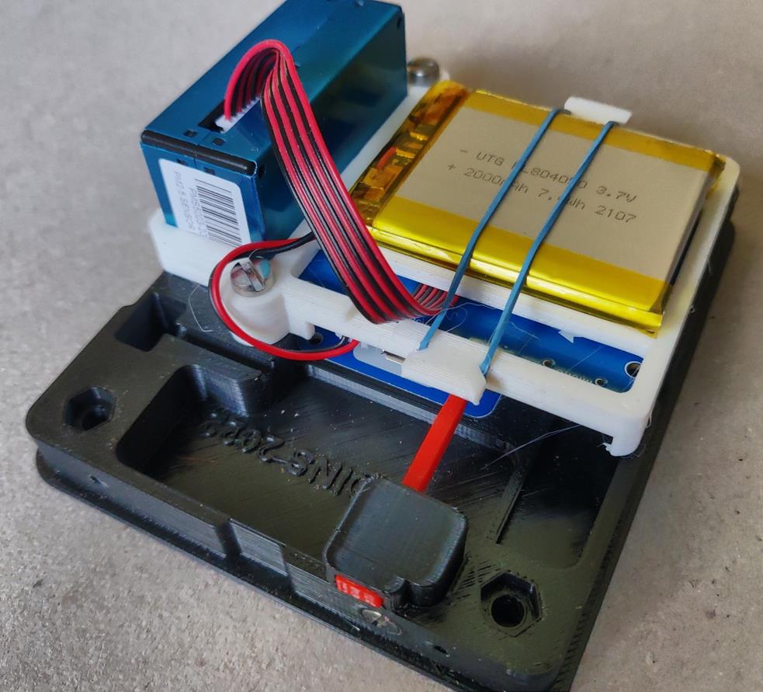
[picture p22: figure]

### 10. Files for 3D print / 3D Druckdateien

Basiseinheit / base-carrier sck_17-basis.stl | sensorrahmen / sensor(PCB) frame sck_17-sensor-rahmen.stl
Tastenstössel / push rod sck_17-tastenstoessel.stl | Tastenführung / buttonguide sck_17-taster-einsatz.stl
Abstandhalter PCB / spacer for PCB sck_17-spacer.stl | Deckel mit Bohrungen / cover with holes sck_17-deckel-mit-bohrungrn.stl

Hinweis: Den Sensorrahmen mit 5 Perimeter drucken
Hint: Print the sensor-frame with 5 perimeters

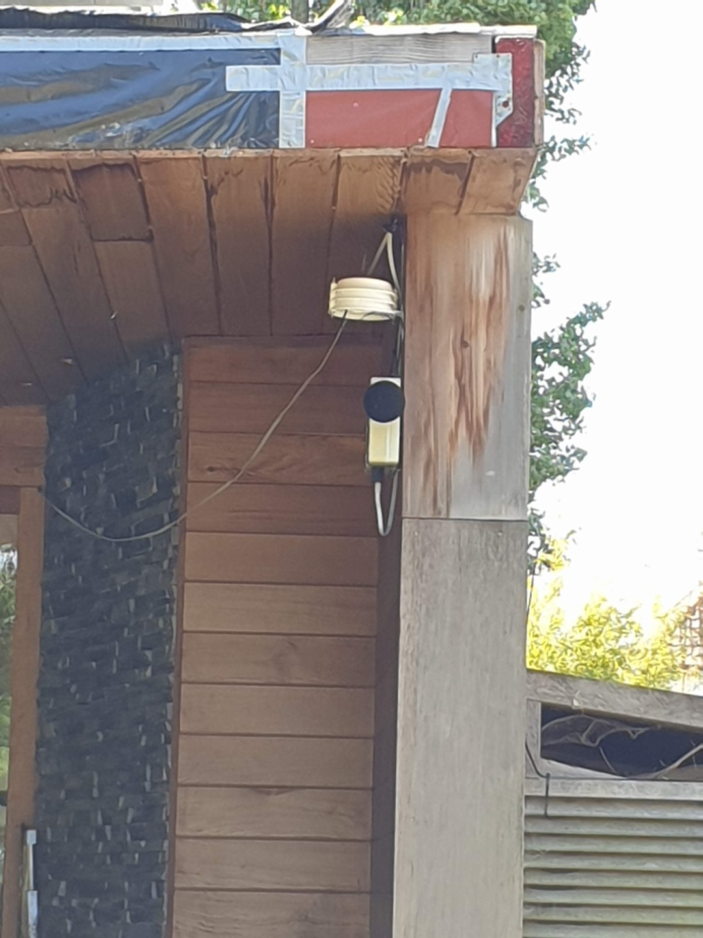
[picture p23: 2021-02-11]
docs/Air/SCK2.1/SCK2.1_PMS5003/3D Printed Modular Viadukaduk/pictures/20200601_115506.jpg

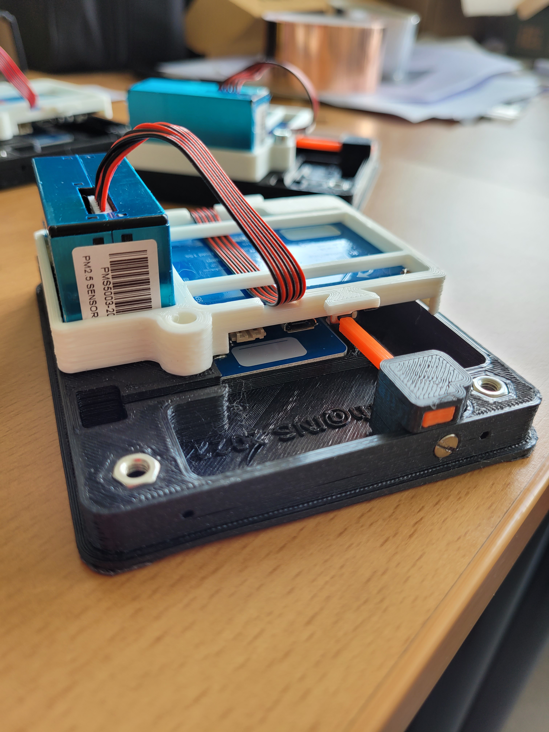
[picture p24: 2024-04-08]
docs/Air/SCK2.1/SCK2.1_PMS5003/SCK_3Dprint_Assembly_GER_EN_USTTG_IIGS_2023/2022-05-16 16.18.14.jpg

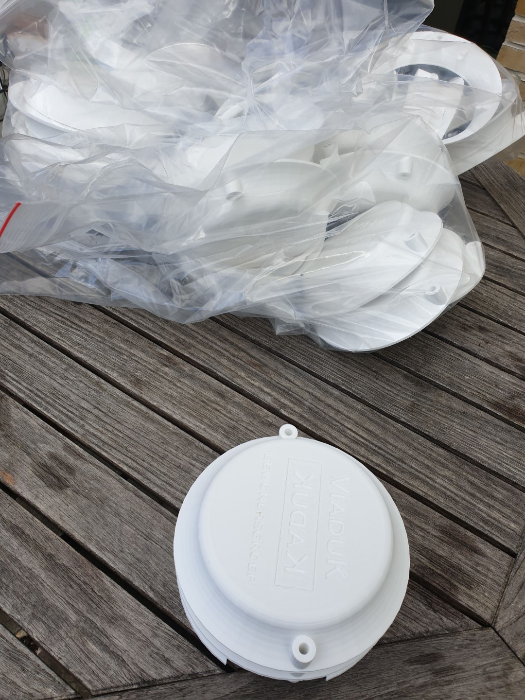
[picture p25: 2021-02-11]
docs/Air/SCK2.1/SCK2.1_PMS5003/3D Printed Modular Viadukaduk/pictures/20200512_170218.jpg

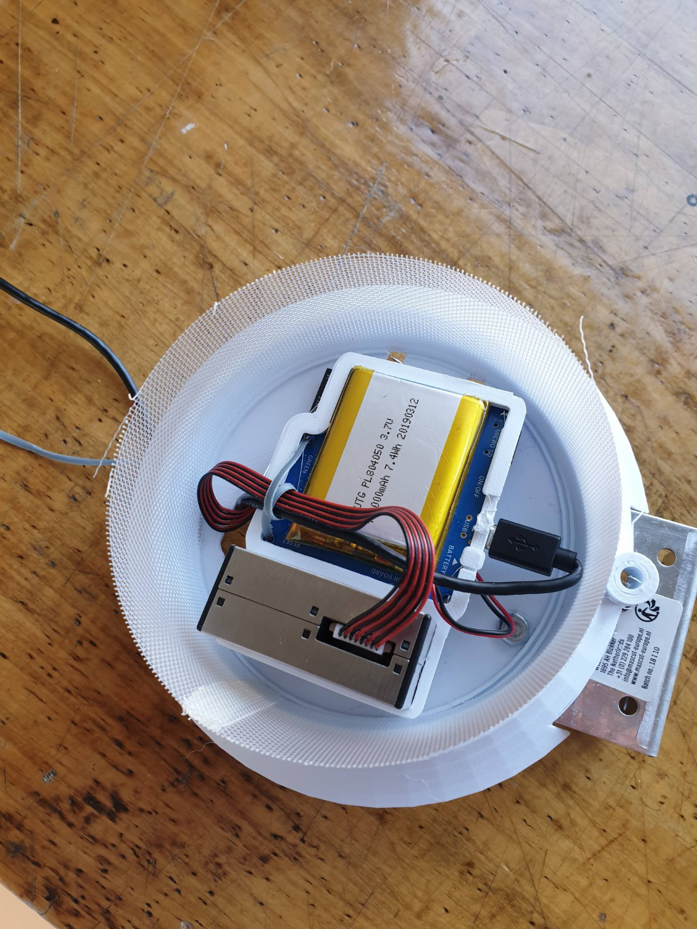
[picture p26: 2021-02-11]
docs/Air/SCK2.1/SCK2.1_PMS5003/3D Printed Modular Viadukaduk/pictures/20200411_113009.jpg

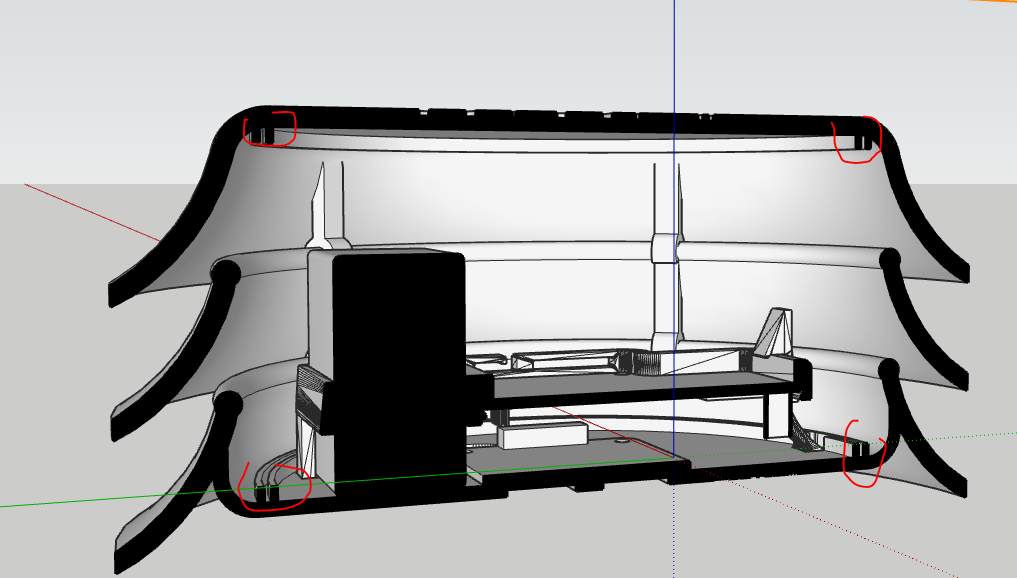
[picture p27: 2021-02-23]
docs/Air/SCK2.1/SCK2.1_PMS5003/3D Printed Modular Viadukaduk/pictures/section_0.2.png

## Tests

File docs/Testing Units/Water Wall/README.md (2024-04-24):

# Water Wall 

A wall to hold and organize the "Testing Units". Made out of wood, with metal inserts on the back to host screws so the units are tightly fixed and they don't fall by mistake. A cable holder for the sensor cables and a water bucket to dip the sensors to be tested.

## Materials
- **Wood panel 2440x1220x9mm** --> As a board to hang all the sensors. With Metal inserts in the back.
- **M4 x 60 Screws** --> Together with a 3d printed wing head for the screw "IP_Box_WingHead_v3.stl" sticked with a drop of glue, so it is easier to screw the Ip boxes of the testing units to the wall.
- **Metal Inserts**  --> Placed into the back of the wood board, to host the Ip boxes screws.
- **M8 Threadded bar** --> Cutted at 140 mm lenght to fit the 3d printed "Cable_Holder_v1.stl".
- **M8 screw Nuts** --> To cover the ends of the thredded bar of the "Cable holder" together with the 3D print "Cable_Holder_Metal_Nut_Cover.stl" to cover the nut.
- **Heatsink tube** --> To cover the threadded bar so its soft and doesn't scratch the sensor cables.
- **Bucket for water** --> Anything around 65L and 65x44x28cm.

## Images
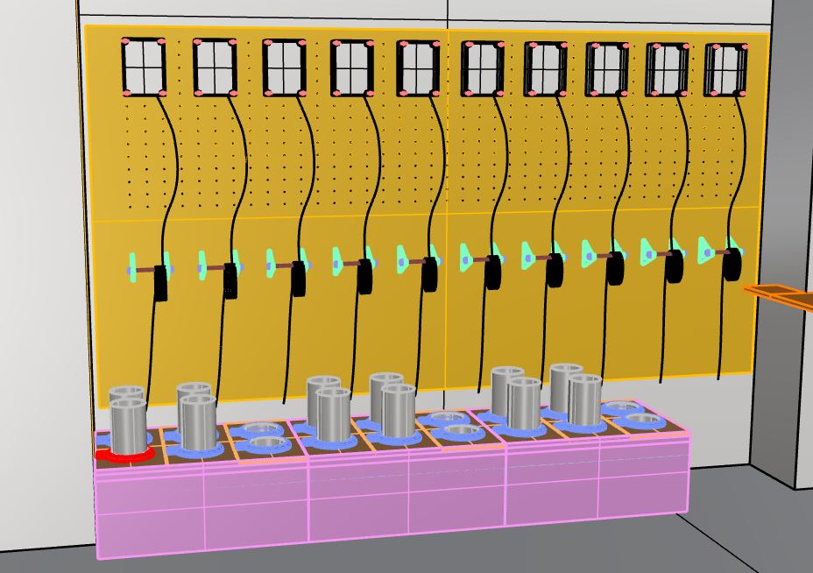
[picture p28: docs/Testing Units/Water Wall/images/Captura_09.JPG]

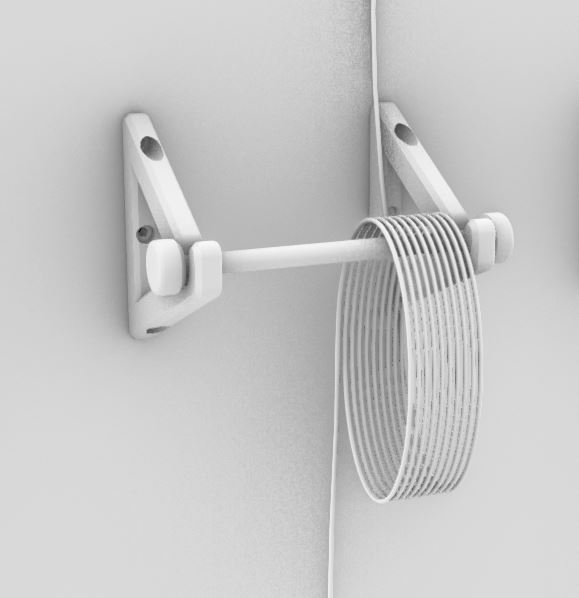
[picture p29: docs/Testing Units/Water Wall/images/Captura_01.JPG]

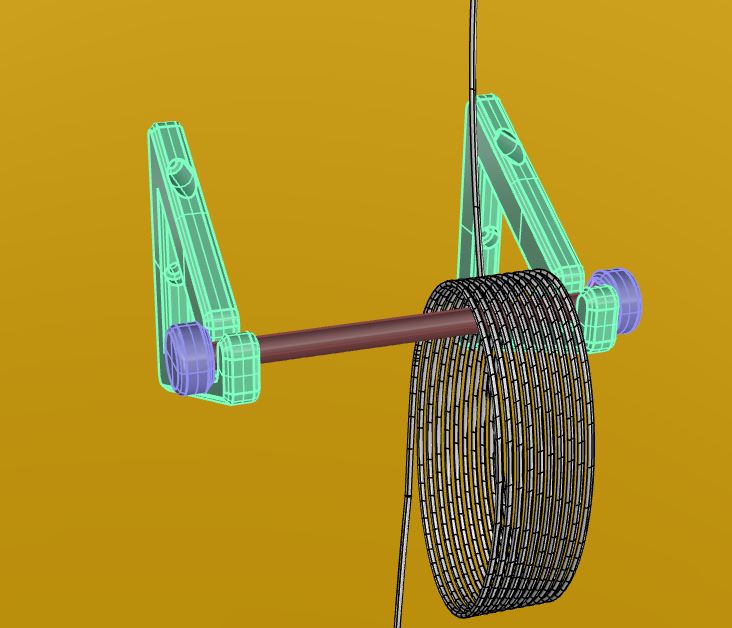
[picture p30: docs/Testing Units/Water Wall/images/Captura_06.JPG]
 
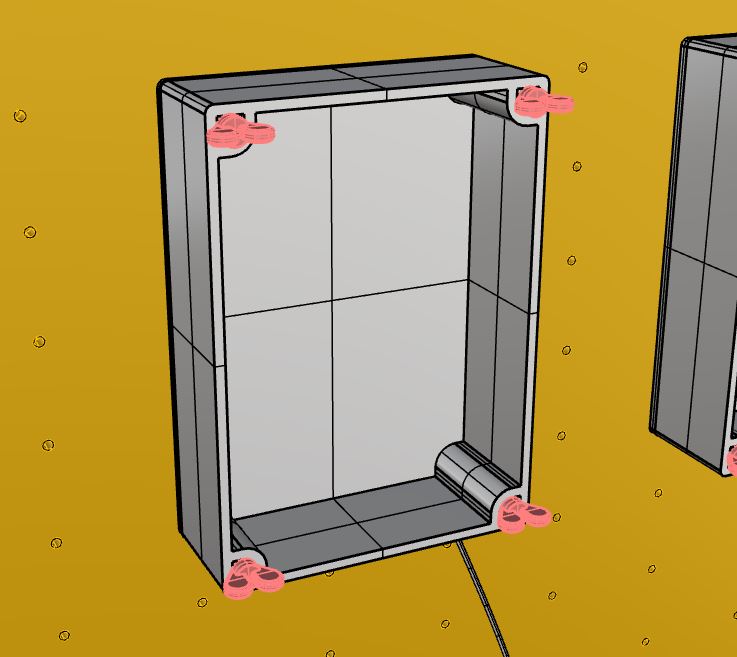
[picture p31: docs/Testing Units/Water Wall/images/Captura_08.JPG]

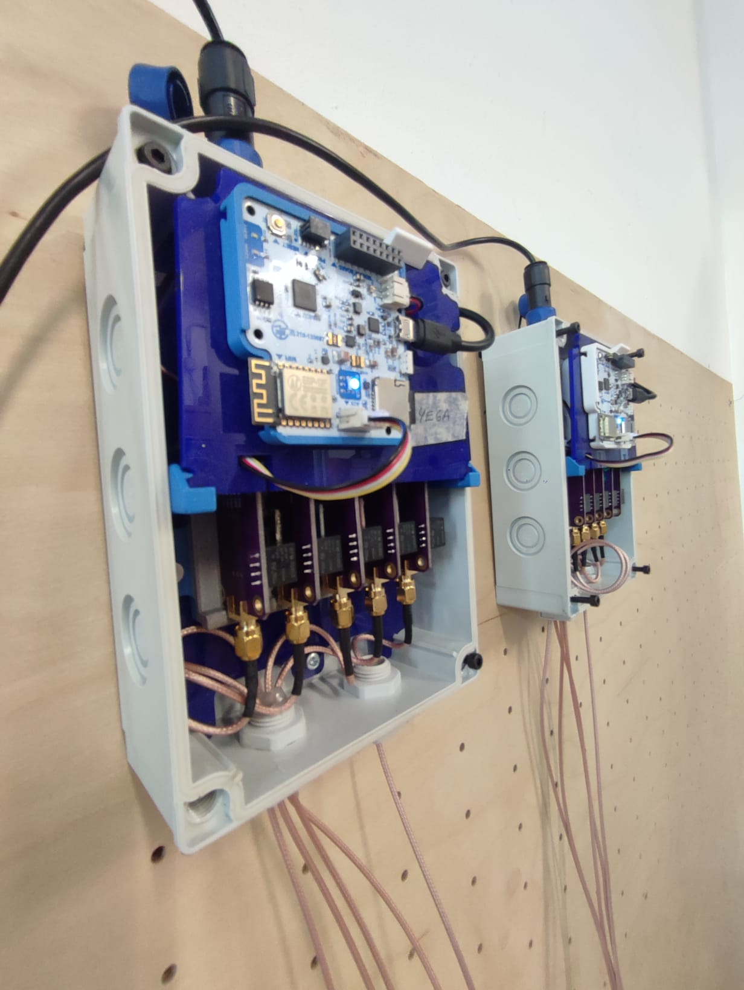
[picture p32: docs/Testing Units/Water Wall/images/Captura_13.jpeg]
 
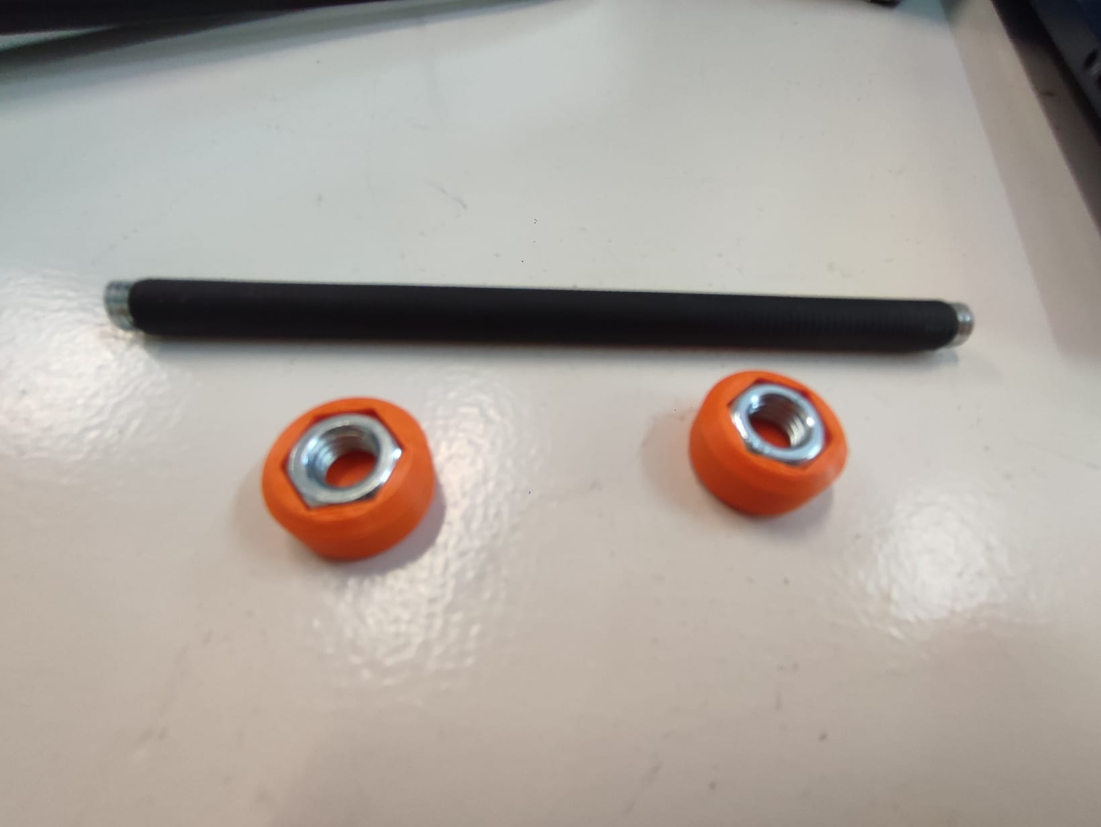
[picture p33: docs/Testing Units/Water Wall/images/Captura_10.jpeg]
 
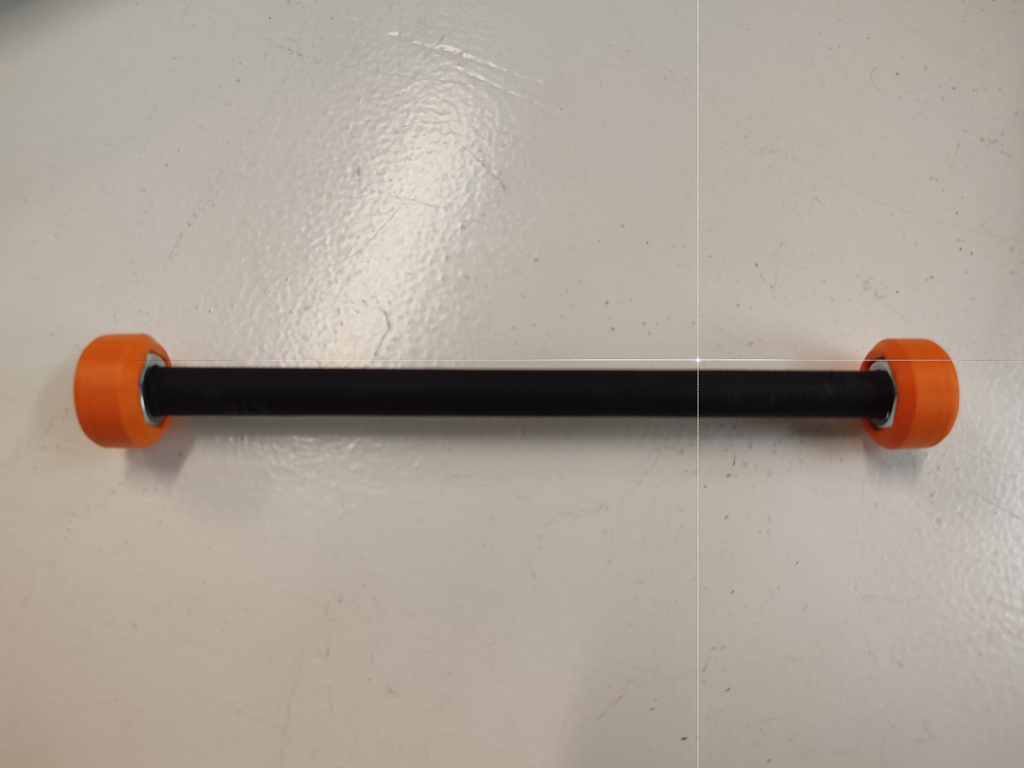
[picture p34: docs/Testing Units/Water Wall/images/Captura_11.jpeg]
 
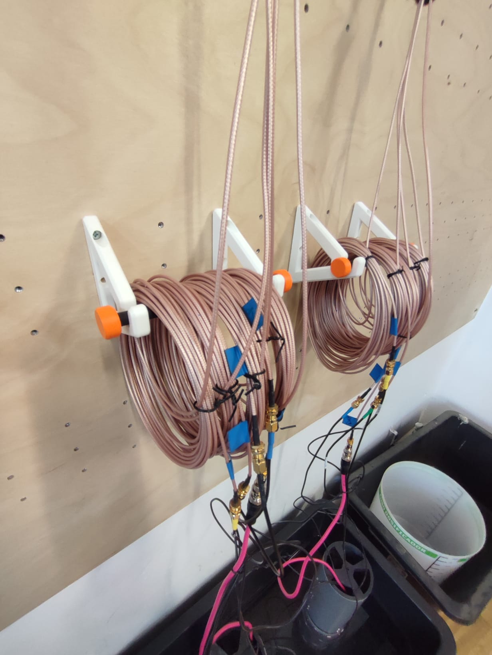
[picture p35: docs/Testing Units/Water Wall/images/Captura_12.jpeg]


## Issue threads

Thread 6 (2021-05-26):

SCK 2.1 DIY Clips | New battery case

bitvijays, 2021-05-26:
Dear Smart Citizen Kit Team,

Hope you are doing well and thank you for creating a amazing SCK kit.

Currently, we have SCK Kit 2.1 which comes with a different battery than the SCK 2.0.  Battery of 2.0 is slimmer and bigger than battery of 2.1.

The [clips of SCK2.1](https://github.com/fablabbcn/smartcitizen-enclosures/blob/master/SmartCitizen%20DIY%20Clips%20V2.0-2.1/3D%20Print%20Clips.stl) enclosures are probably created for 2.0 and not 2.1 battery?

Would it be possible to provide Clips 2.1 with battery which is smaller and thicker?

Yours Sincerely,
Vijay

oscgonfer, 2021-06-05:
Hi!

The clips in the SCK2.1 are meant for a small 2000mAh battery. This image shows clearly how they are put together:
https://www.flickr.com/photos/smartcitizen/51139782953/

In the case of SCK2.0, the battery then was larger in footprint but thinner. The clips (which I wouldn't recommend using) held the battery like so:
https://www.flickr.com/photos/smartcitizen/45269792052/

The battery in this latter case is held and potentially pressed by the clips, not leaving room for dilatation. Let us know if, with these comments, the SCK2.1 clips work now (we moved them here):  https://github.com/fablabbcn/smartcitizen-enclosures/blob/master/SmartCitizen%20Outdoor%20Cases%20V2.*/SCK2.1_PMS5003/HDPE%20circle/components/CLIP_NO_ORING.stl

bitvijays, 2021-06-24:
Thank you @oscgonfer 👍 That's really helpful.

Closed 2021-06-24.

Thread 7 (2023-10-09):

Documenting Water Enclosures

oscgonfer, 2023-10-09:
Most prominent things to document:

**Stations**
- [ ] https://github.com/fablabbcn/smartcitizen-enclosures/blob/master/SmartCitizen%20Water%20Enclosures/SmartCitizen%20Water%20Station/README.md
- [ ] https://github.com/fablabbcn/smartcitizen-enclosures/tree/master/SmartCitizen%20Water%20Enclosures/SmartCitizen%20Water%20Station/Isolated%20Carriers%20Station (and add photos!)

**Probe holders**
- [ ] https://github.com/fablabbcn/smartcitizen-enclosures/tree/master/SmartCitizen%20Water%20Enclosures/Probe%20Holders/bulk
- [ ] https://github.com/fablabbcn/smartcitizen-enclosures/tree/master/SmartCitizen%20Water%20Enclosures/Probe%20Holders/linear

oscgonfer, 2024-05-04:
Some stuff pushed in [bbcd598ad6c7c21b01233264a9d4417d3867d2aa](https://github.com/fablabbcn/smartcitizen-enclosures/commit/bbcd598ad6c7c21b01233264a9d4417d3867d2aa), but some pending to-dos @peters-rebecca @adaisuri

Closed 2025-02-17.

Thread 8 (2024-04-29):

SCK 2.X Enclosures

oscgonfer, 2024-04-29:
Brief list of issues here.@peters-rebecca , please open a separate one for the findings on other models.

* [ ] Improve cabling on SCK 2.X enclosures for better management of reset and PM cable
* [ ] Tolerance of SCK 2.X enclosures for the Urban Board gap

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

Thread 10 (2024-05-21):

SCK 2.2 CO2 + HCHO

peters-rebecca, 2024-05-21:
Issues to fix on the base:

- [ ] Verify sizes and depths of holes are consistent (for the last batch there were issues with filament getting inside the inserts because the holes were too small).
- [ ] Ribbing for second set of raised inserts is missing and can lead to breaking (see image).

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

Link to the file:
https://github.com/fablabbcn/smartcitizen-enclosures/blob/master/SmartCitizen%20Air%20Enclosures/SCK2.2/SCK2.2%20with%20PM%20Sensor%20and%20Extras/Small%20Versions/S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

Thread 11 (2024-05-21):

SCK 2.2 EC

peters-rebecca, 2024-05-21:
Issues to fix on the base:

- [ ] Verify sizes and depths of holes are consistent (for the last batch there were issues with filament getting inside the inserts because the holes were too small).

Link to the https://github.com/fablabbcn/smartcitizen-enclosures/blob/master/SmartCitizen%20Air%20Enclosures/SCK2.2/SCK2.2%20with%20PM%20Sensor%20and%20Extras/Small%20Versions/S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

Closed 2025-01-24.

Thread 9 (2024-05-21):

SCK Frog Boxes (Latch Holes)

peters-rebecca, 2024-05-21:
The latch holes should be double checked on all versions (with wider hole on the outer sides), especially where the M3x30 goes on the enclosure base to secure the latch (see photo). The filament breaks slightly because the size of the INOX screw is too large on the far side.

So far, I have found the issue on the following versions:

- [ ] 2.1 Indoor (https://github.com/fablabbcn/smartcitizen-enclosures/tree/master/SmartCitizen%20Air%20Enclosures/SCK2.1/SCK2.1%20with%20PM%20Sensor/SCK2.1_PMS5003/3D%20Printed%20fro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)

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

Closed 2025-01-24.

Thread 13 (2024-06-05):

SCK2.2 Outdoor

oscgonfer, 2024-06-05:
- [x] Improve a bit the tolerances on the outdoor screws
- [x] Improve the position where the M4 screw from the umbrella blocks the lid (make more robust)

Closed 2025-01-24.

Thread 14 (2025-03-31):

Clip breaks too easily

oscgonfer, 2025-03-31:
The clip for the SCK2.3 breaks too easily on this spot with the new cable:

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

I suggest:
- [ ] make a solid infill on that area for the printing
- [ ] increase the height so that the slot is wider and the cable fits better into it - right now its too tight

@peters-rebecca please add more feedback in this issue so that @adaisuri can make the necessary changes
Thanks!

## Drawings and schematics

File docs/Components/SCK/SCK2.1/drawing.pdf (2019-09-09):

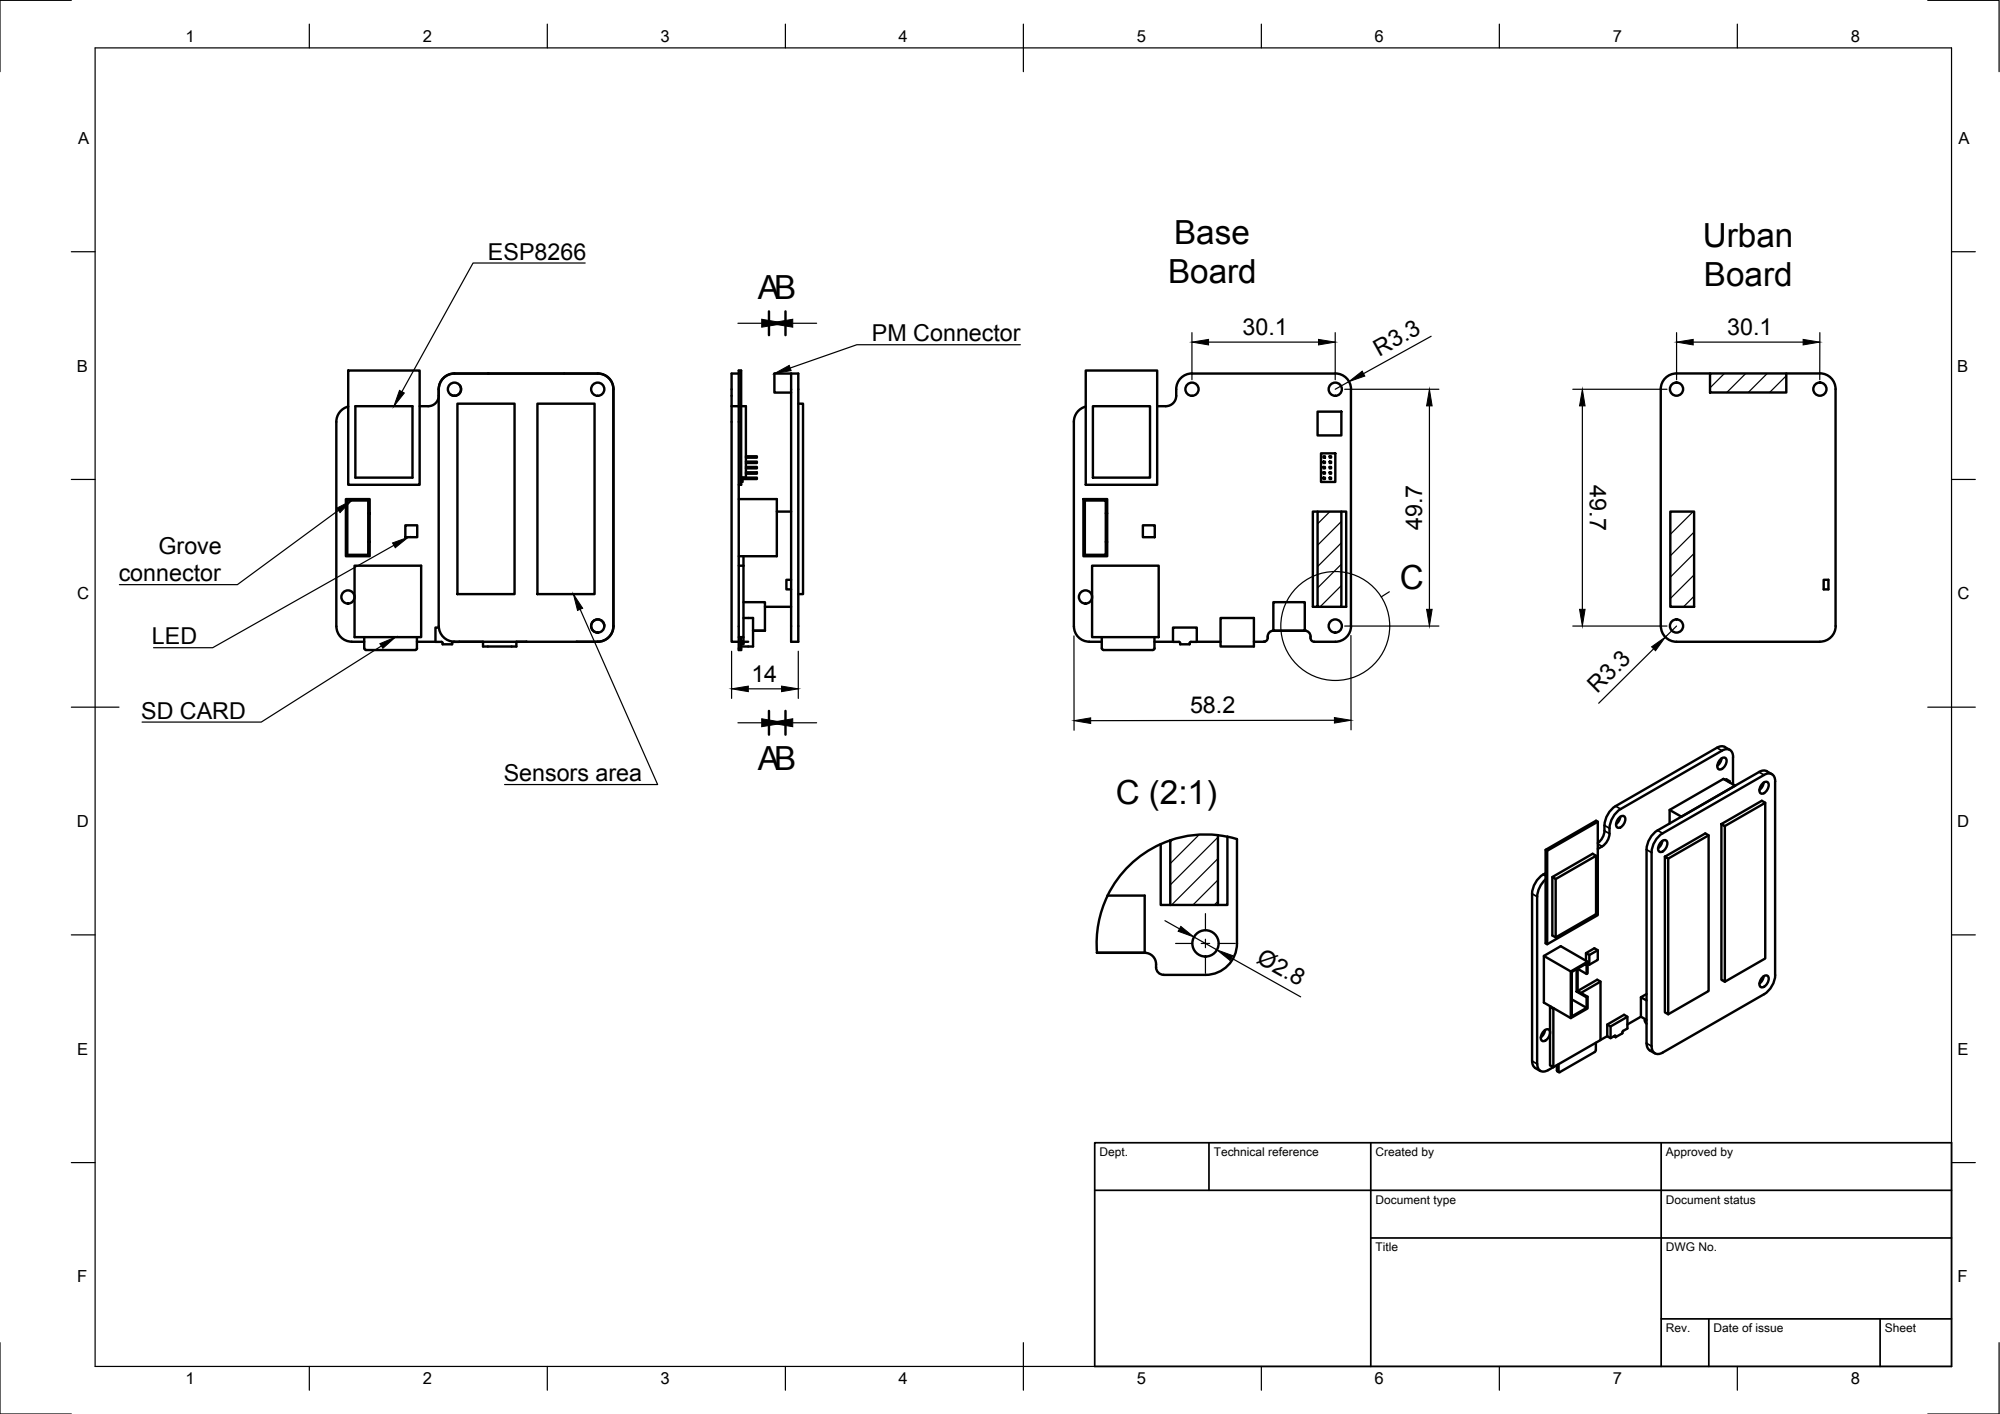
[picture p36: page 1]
SD CARD; Sensors area; PM Connector

Dept. | Technical reference | Created by | Approved by

Document type | Document status

Title | DWG No.

Rev. | Date of issue | Sheet

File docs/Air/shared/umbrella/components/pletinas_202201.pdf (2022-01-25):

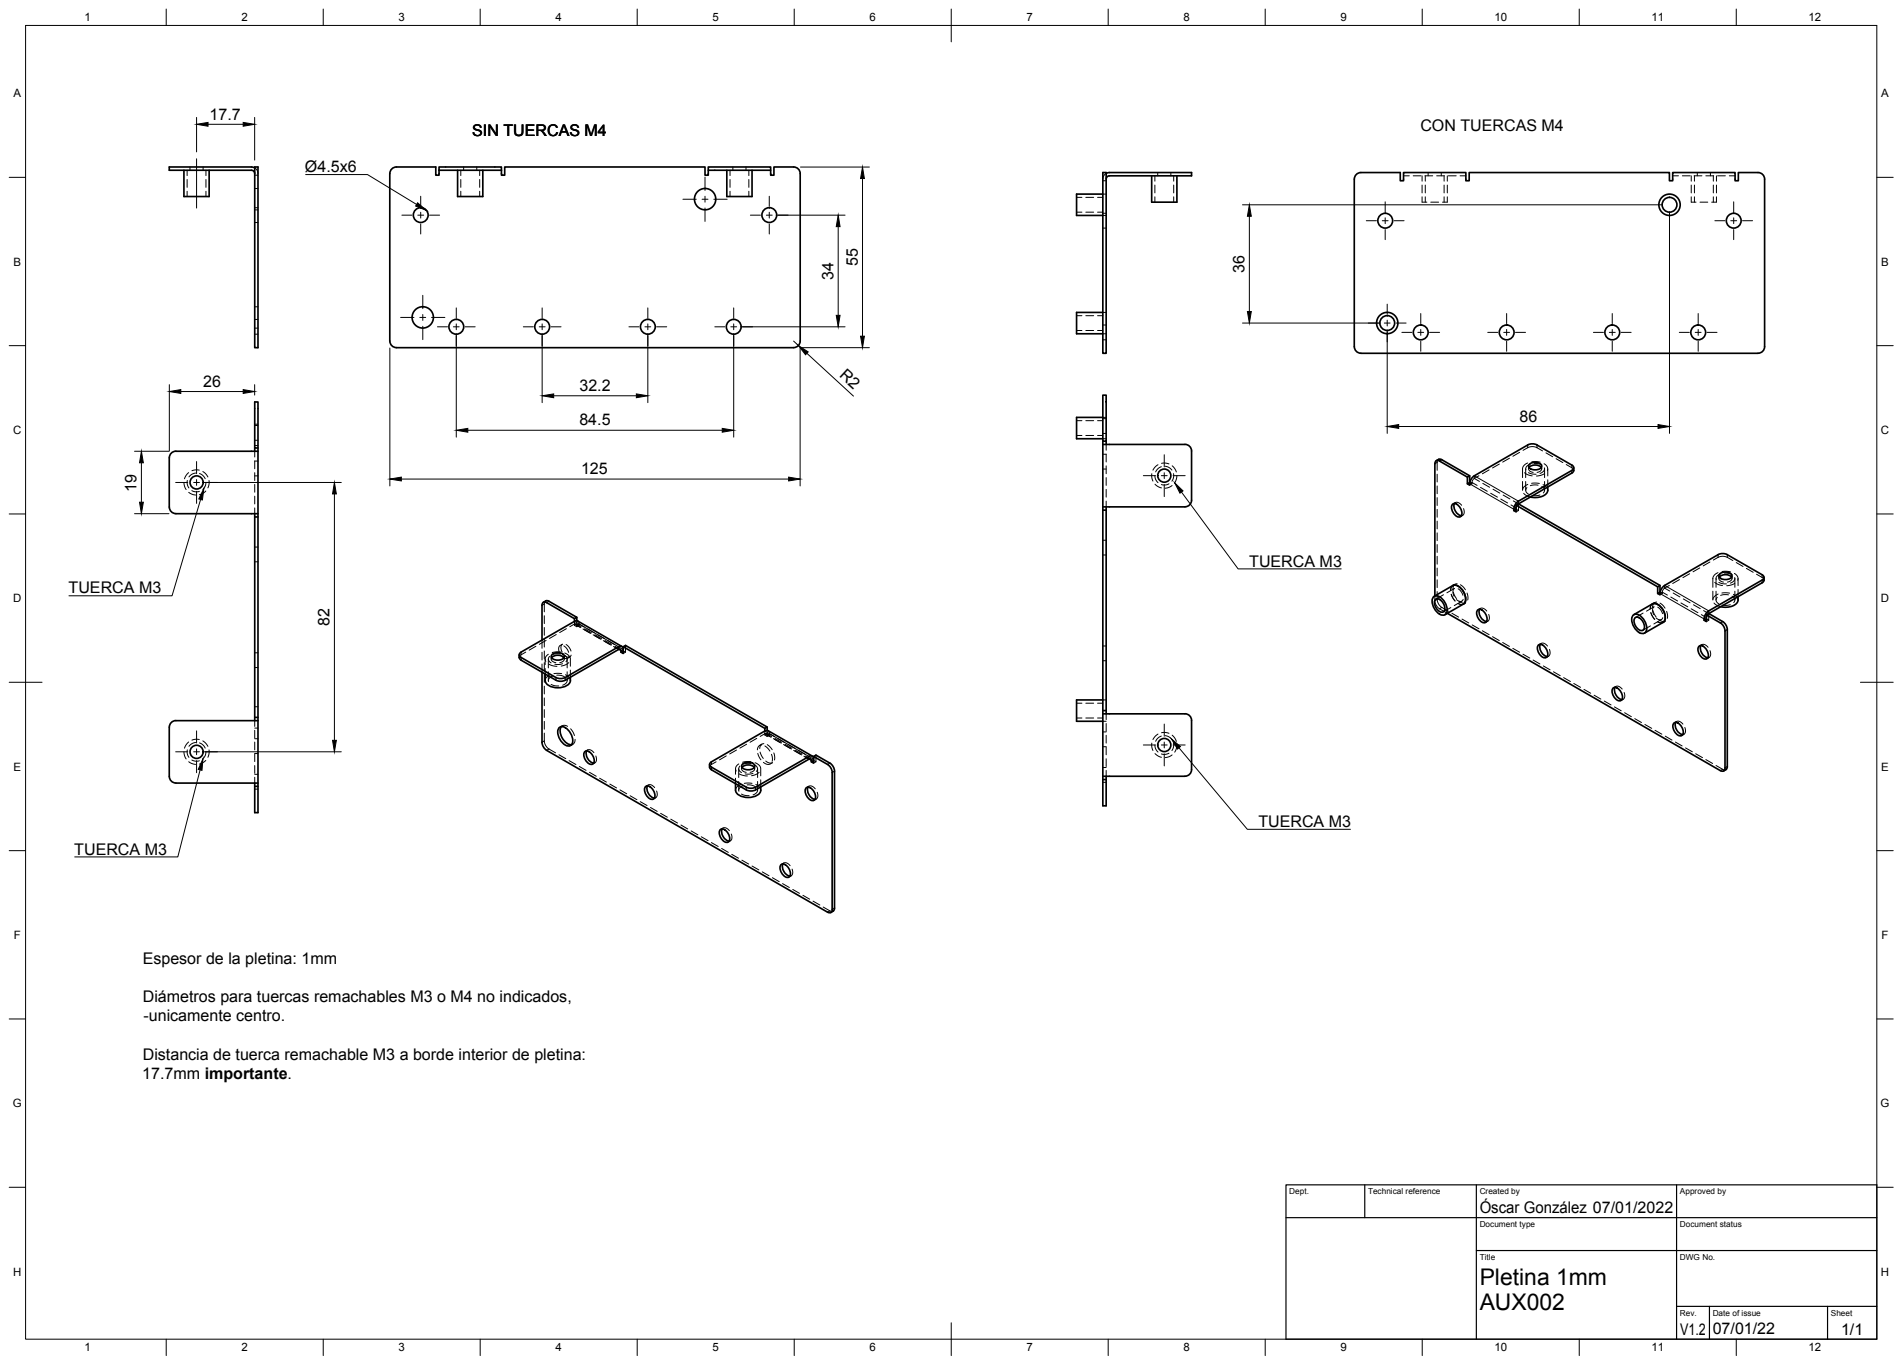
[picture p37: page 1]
SIN TUERCAS M4; CON TUERCAS M4; TUERCA M3

Espesor de la pletina: 1mm

Diámetros para tuercas remachables M3 o M4 no indicados,
-unicamente centro.

Distancia de tuerca remachable M3 a borde interior de pletina:
17.7mm importante.

Dept. | Technical reference | Created by Óscar González 07/01/2022 | Approved by

Document type | Document status

Title Pletina 1mm AUX002 | DWG No.

Rev. V1.2 | Date of issue 07/01/22 | Sheet 1/1

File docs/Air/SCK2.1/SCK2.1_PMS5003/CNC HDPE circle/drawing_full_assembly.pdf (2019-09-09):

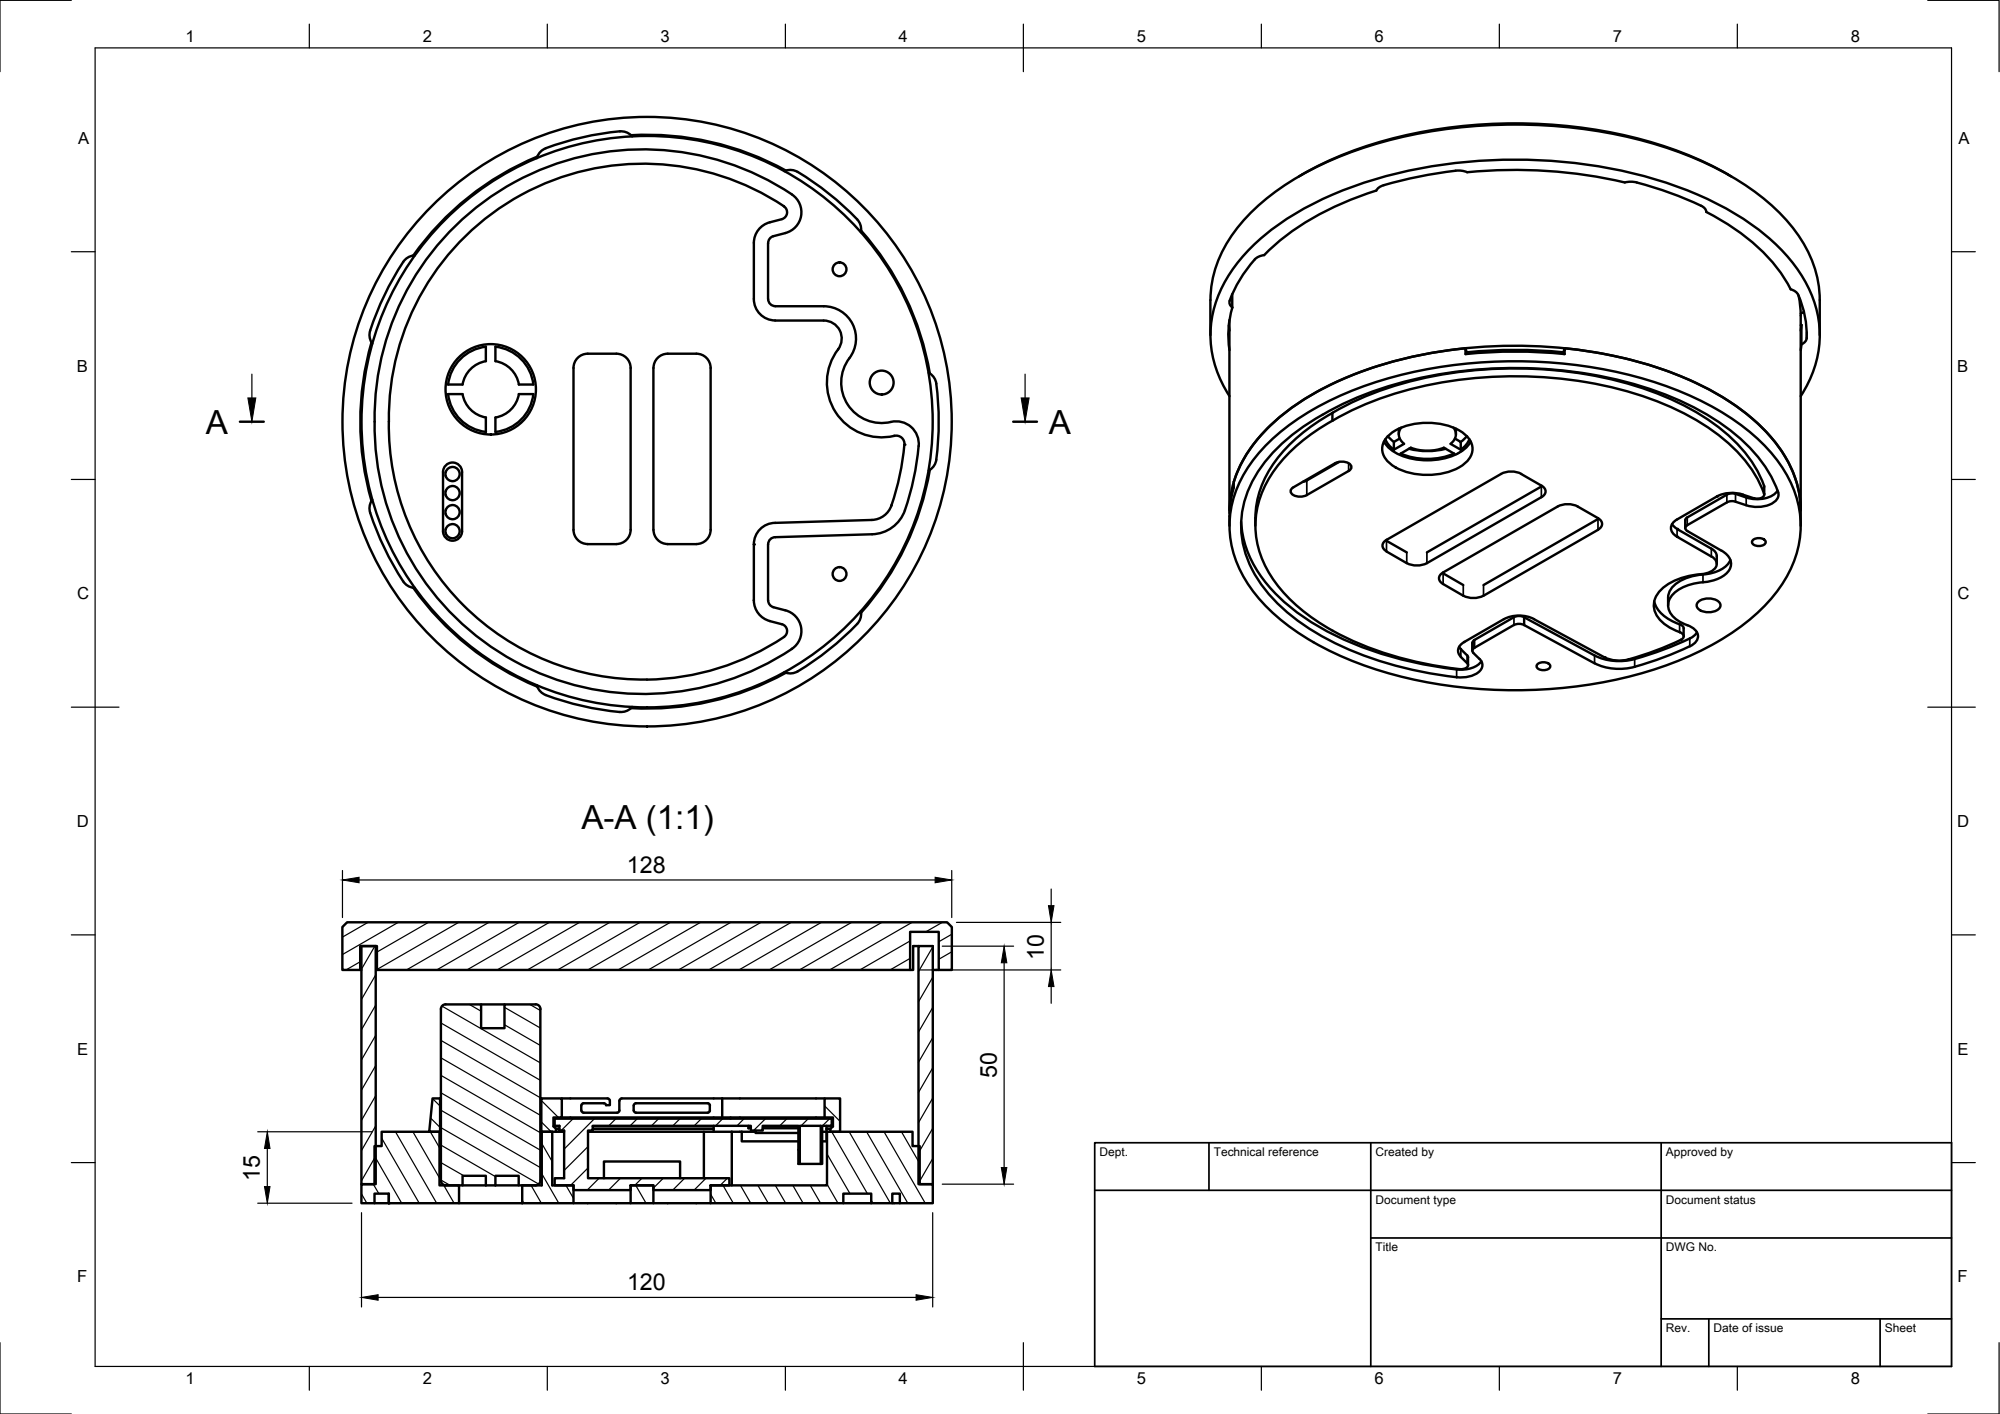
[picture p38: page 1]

Dept. | Technical reference | Created by | Approved by

Document type | Document status

Title | DWG No.

Rev. | Date of issue | Sheet

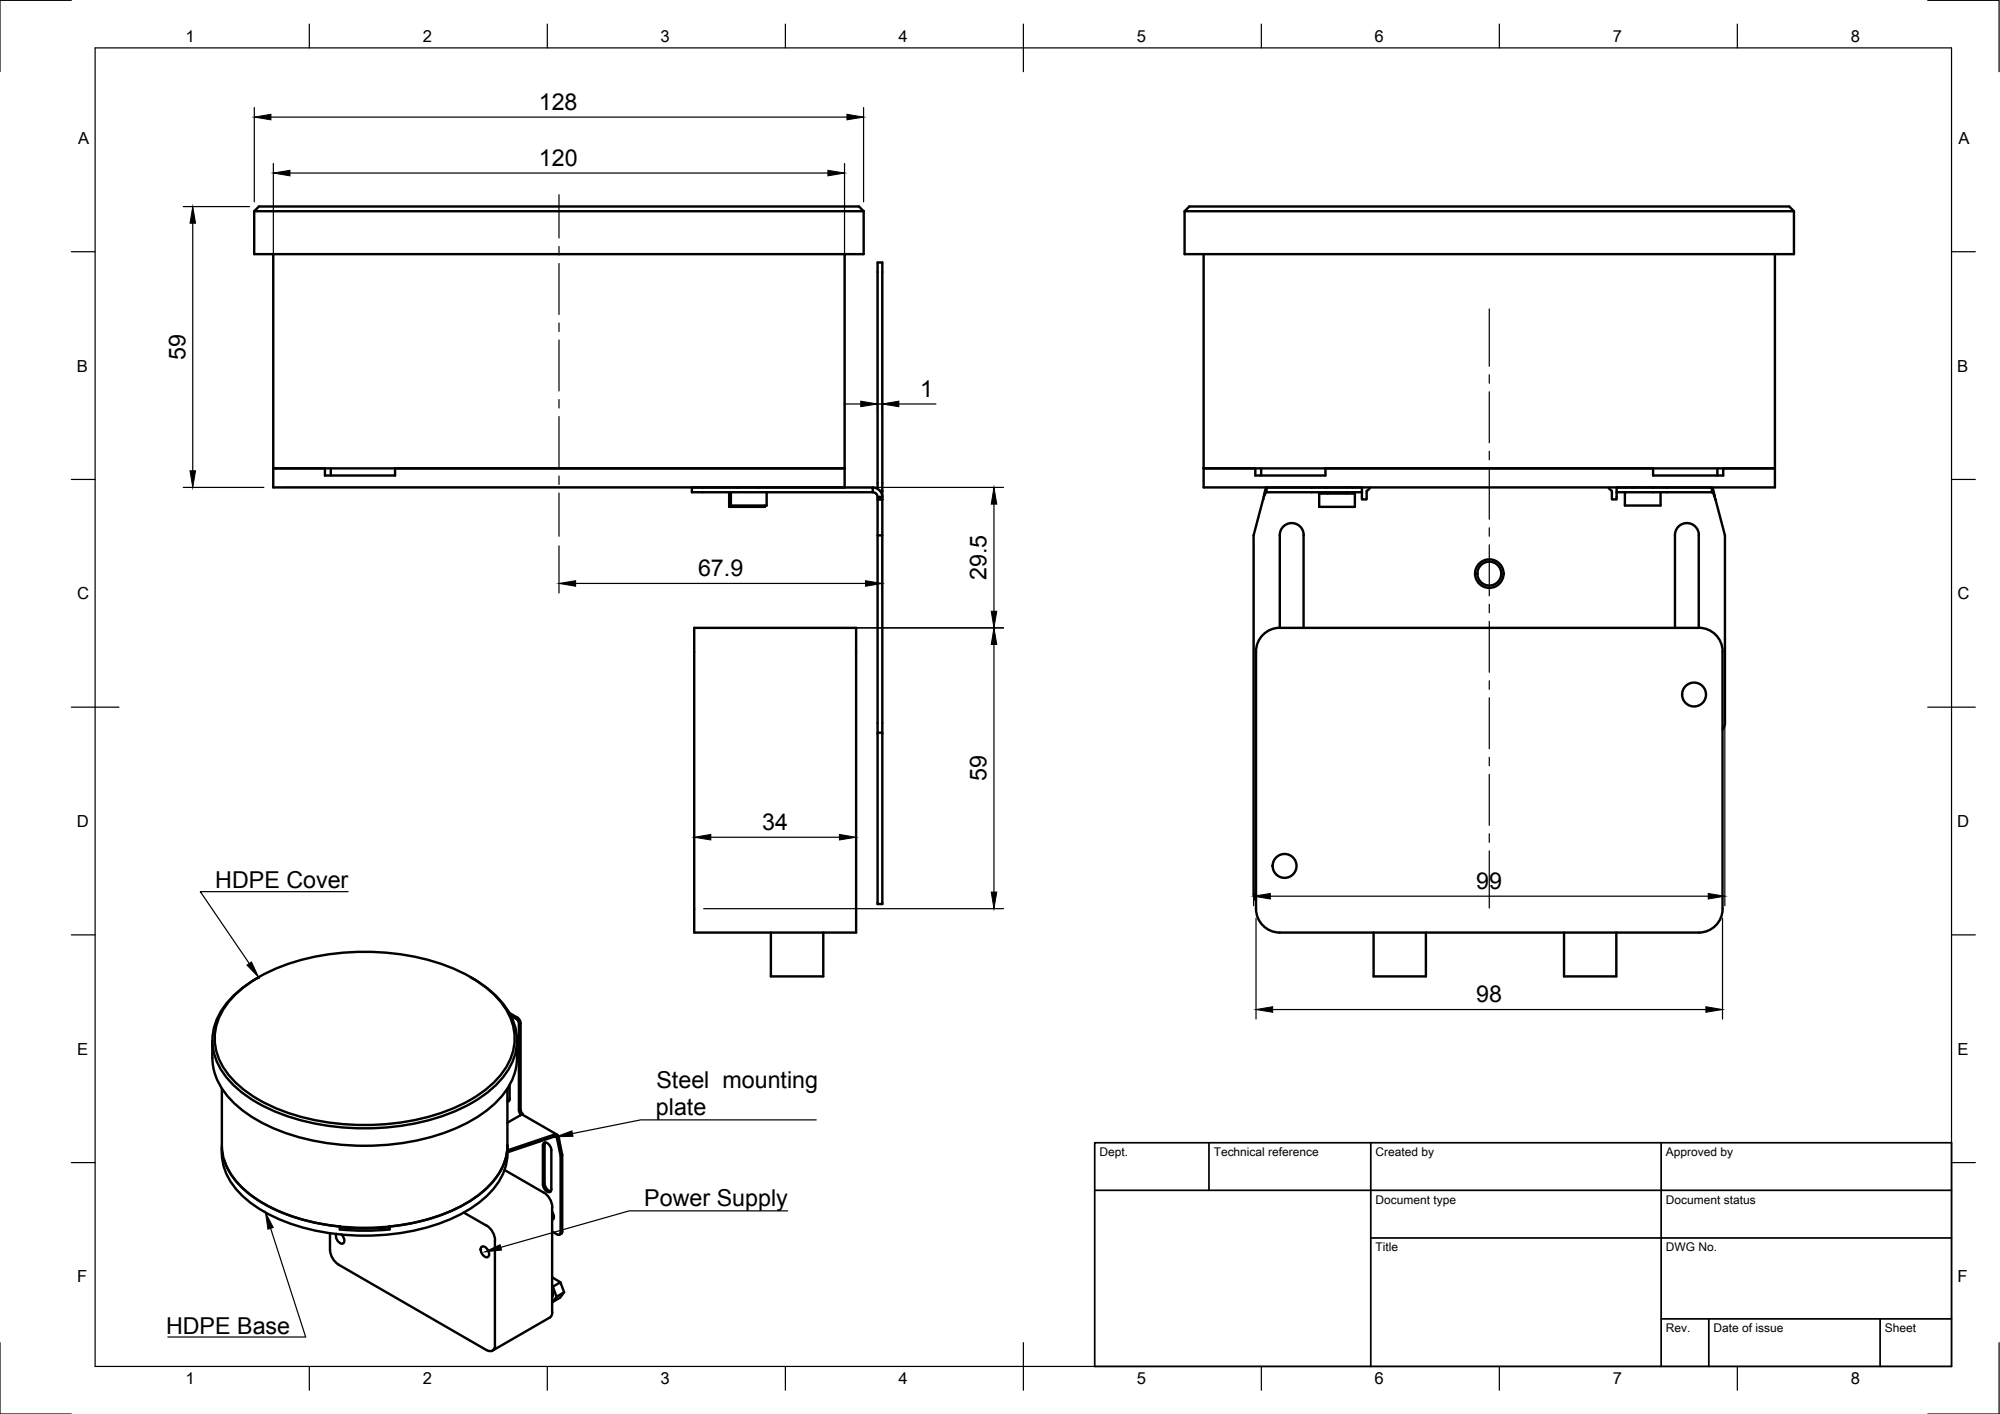
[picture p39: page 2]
Power Supply; Steel mounting; HDPE Cover; HDPE Base

Dept. | Technical reference | Created by | Approved by

Document type | Document status

Title | DWG No.

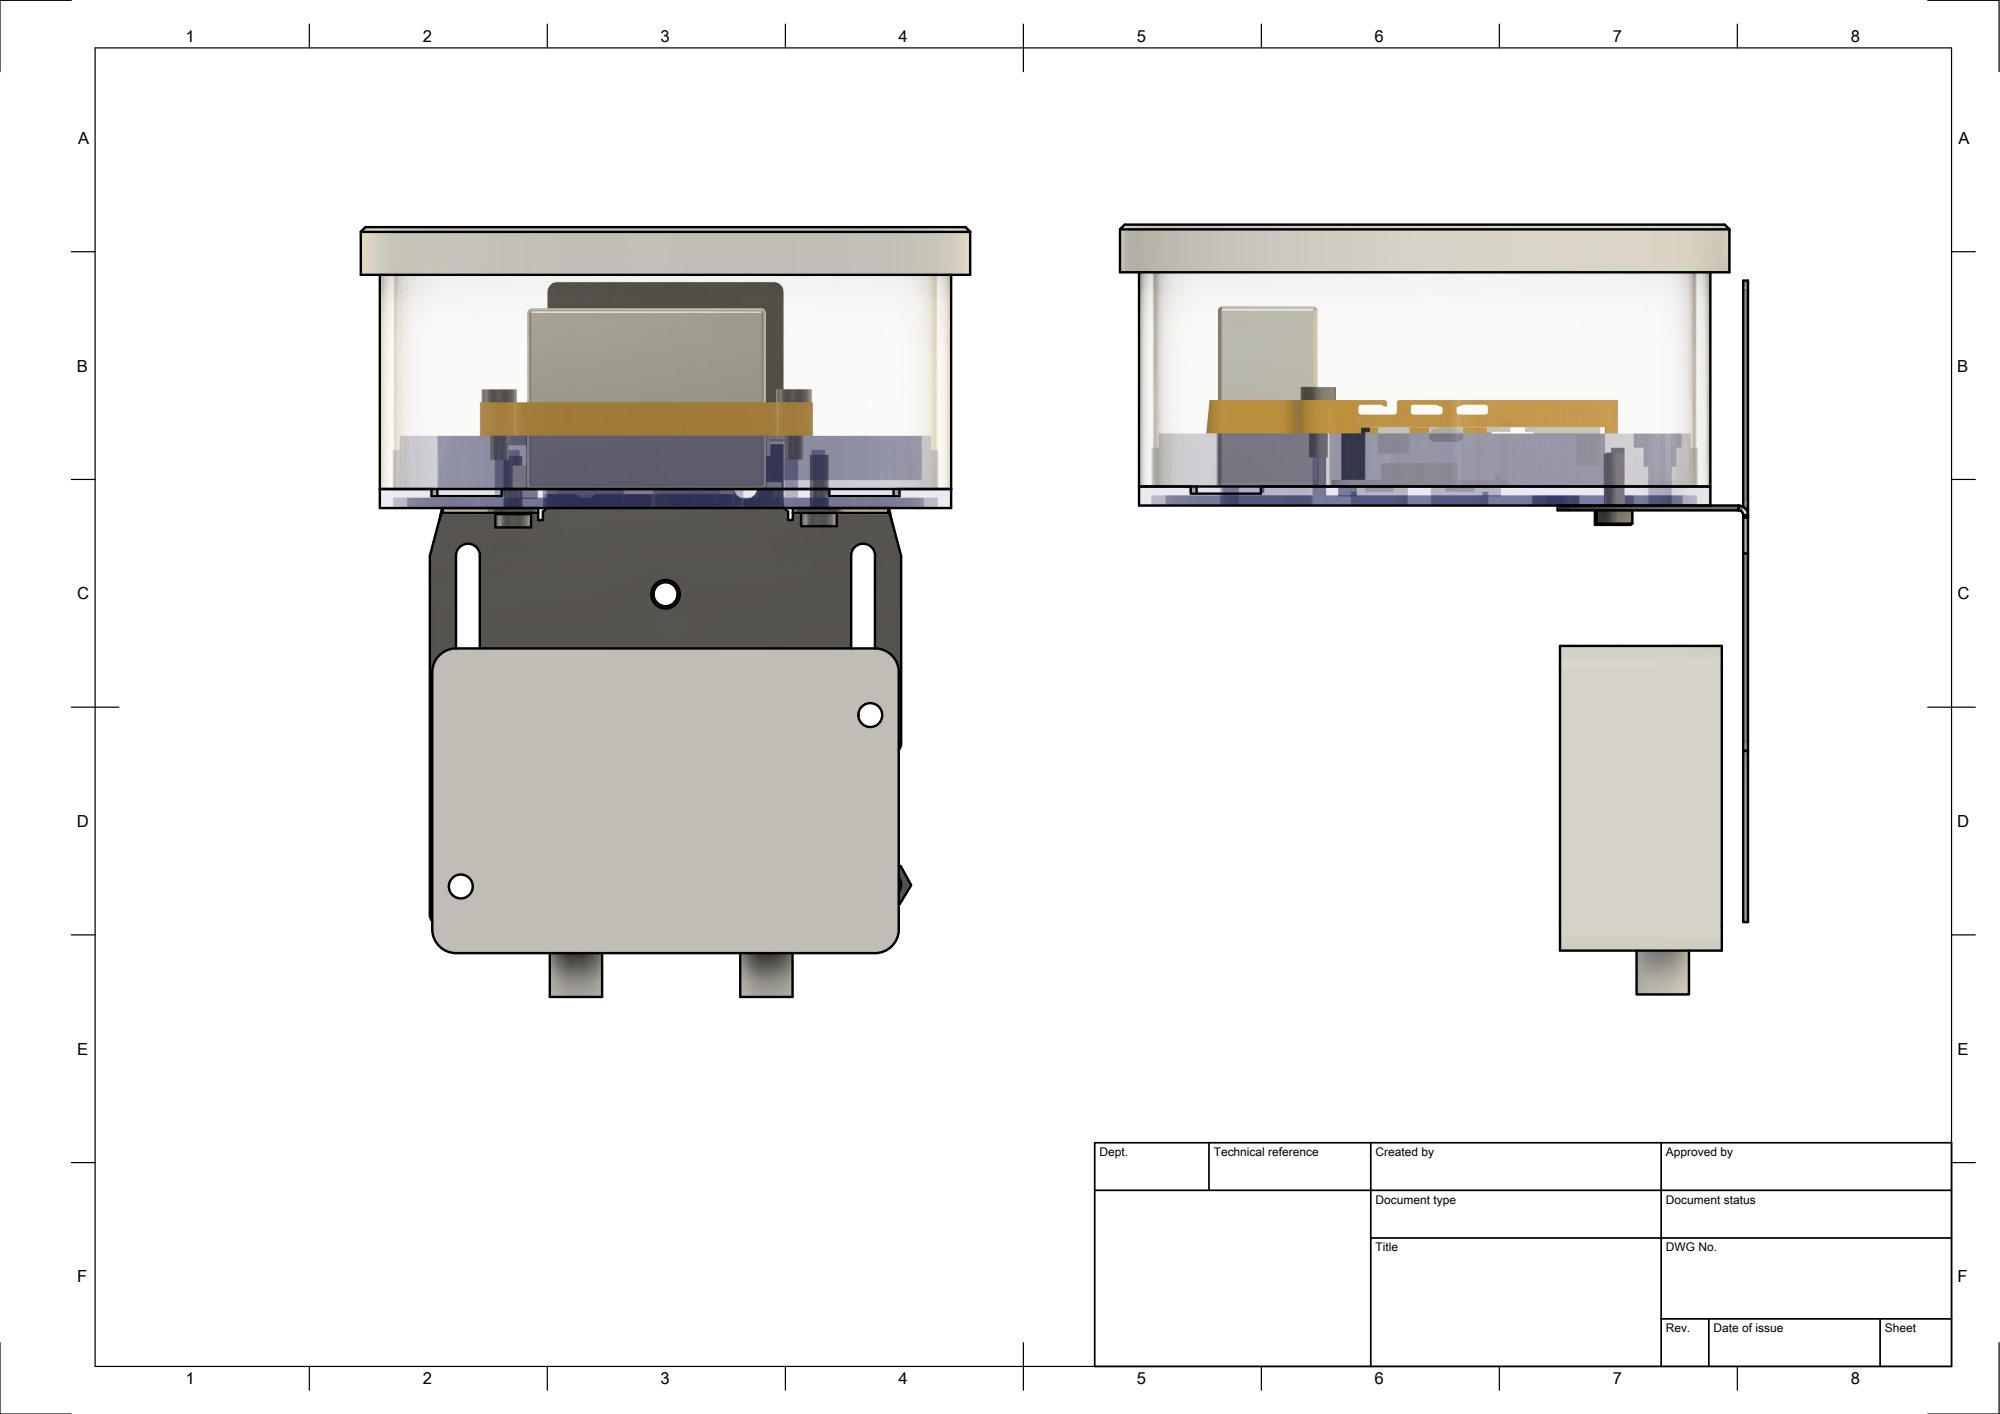
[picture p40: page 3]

Dept. | Technical reference | Created by | Approved by

Document type | Document status

Title | DWG No.

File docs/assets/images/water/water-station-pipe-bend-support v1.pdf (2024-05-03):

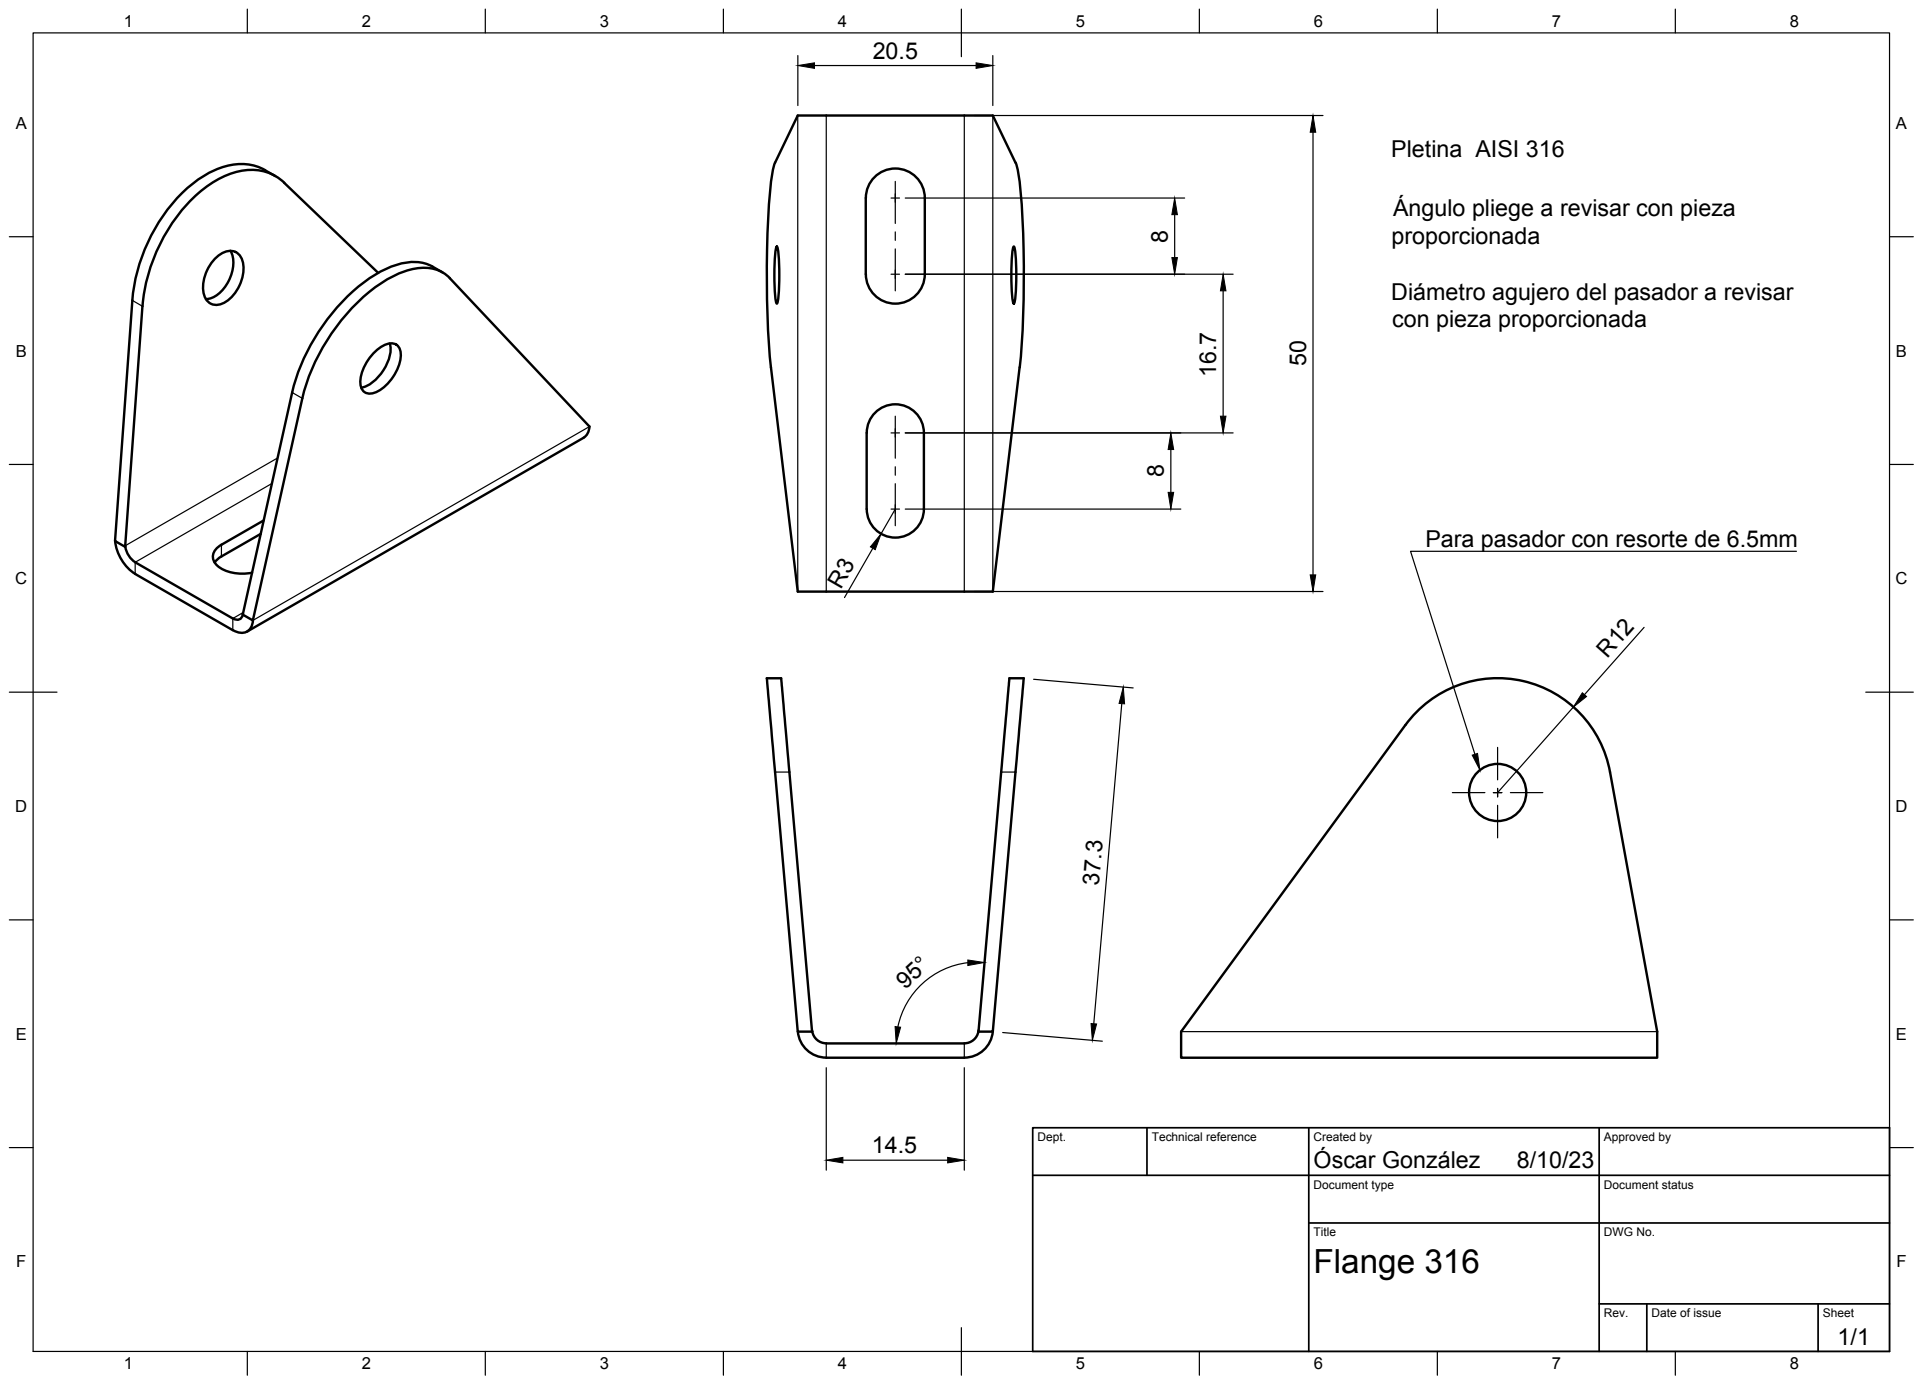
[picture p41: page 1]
Title; DWG No.; Rev.; Date of issue; Sheet; Flange 316; Pletina AISI 316

Ángulo pliege a revisar con pieza
proporcionada

Diámetro agujero del pasador a revisar
con pieza proporcionada

Para pasador con resorte de 6.5mm

Dept. | Technical reference | Created by Óscar González 8/10/23 | Approved by

Document type | Document status

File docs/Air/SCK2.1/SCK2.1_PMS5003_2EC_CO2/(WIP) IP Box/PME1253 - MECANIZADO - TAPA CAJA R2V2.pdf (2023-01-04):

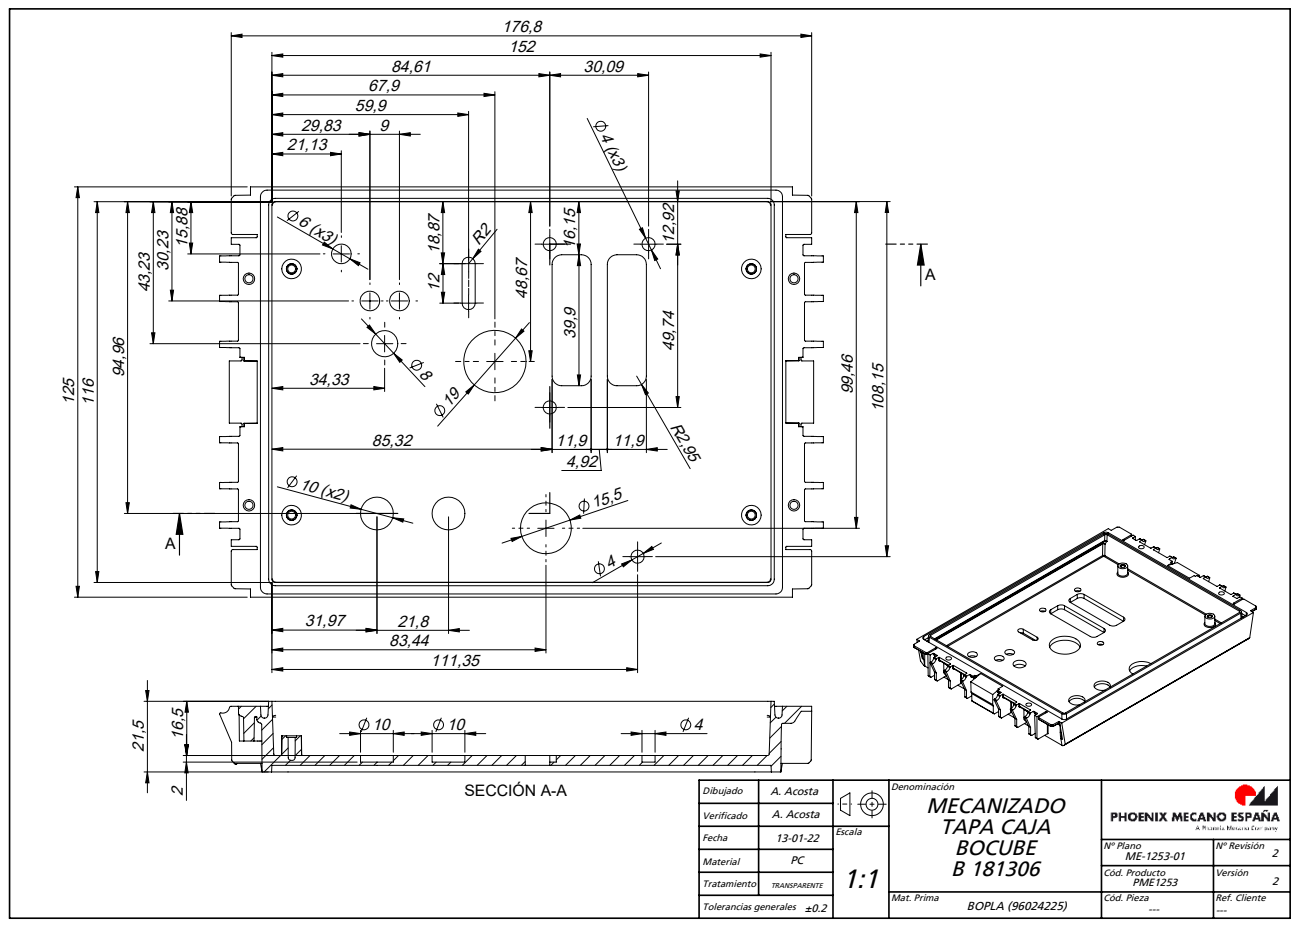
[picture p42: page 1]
SECCIÓN A-A; Tolerancias generales

Dibujado | A. Acosta | | Denominación MECANIZADO TAPA CAJA BOCUBE
Fecha | 13-01-22 | Escala 1:1 | B 181306 PC

Verificado | A. Acosta

Nº Plano ME-1253-01 | Nº Revisión 2

Material

Cód. Producto PME1253 | Versión 2

Tratamiento | TRANSPARENTE

Mat. Prima BOPLA (96024225) | Cód. Pieza --- | Ref. Cliente ---

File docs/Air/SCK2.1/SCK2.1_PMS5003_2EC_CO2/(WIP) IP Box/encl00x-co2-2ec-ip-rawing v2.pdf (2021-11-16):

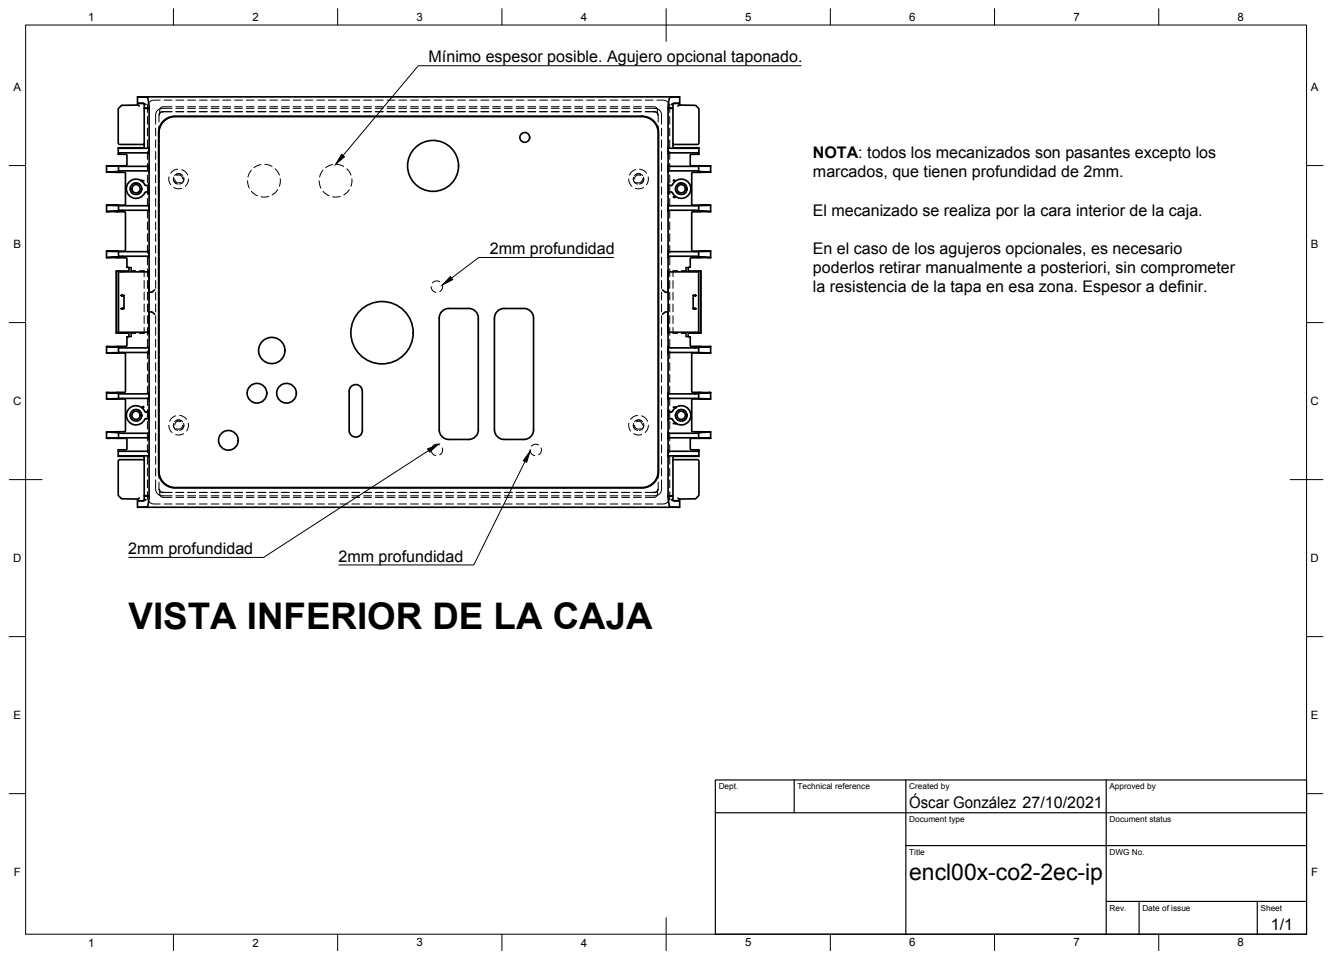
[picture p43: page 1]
Title; DWG No.; Rev.; Date of issue; Sheet; 2mm profundidad

Mínimo espesor posible. Agujero opcional taponado.

NOTA: todos los mecanizados son pasantes excepto los
marcados, que tienen profundidad de 2mm.

El mecanizado se realiza por la cara interior de la caja.

En el caso de los agujeros opcionales, es necesario
poderlos retirar manualmente a posteriori, sin comprometer
la resistencia de la tapa en esa zona. Espesor a definir.

2mm profundidad
VISTA INFERIOR DE LA CAJA

Dept. | Technical reference | Created by Óscar González 27/10/2021 | Approved by

Document type | Document status

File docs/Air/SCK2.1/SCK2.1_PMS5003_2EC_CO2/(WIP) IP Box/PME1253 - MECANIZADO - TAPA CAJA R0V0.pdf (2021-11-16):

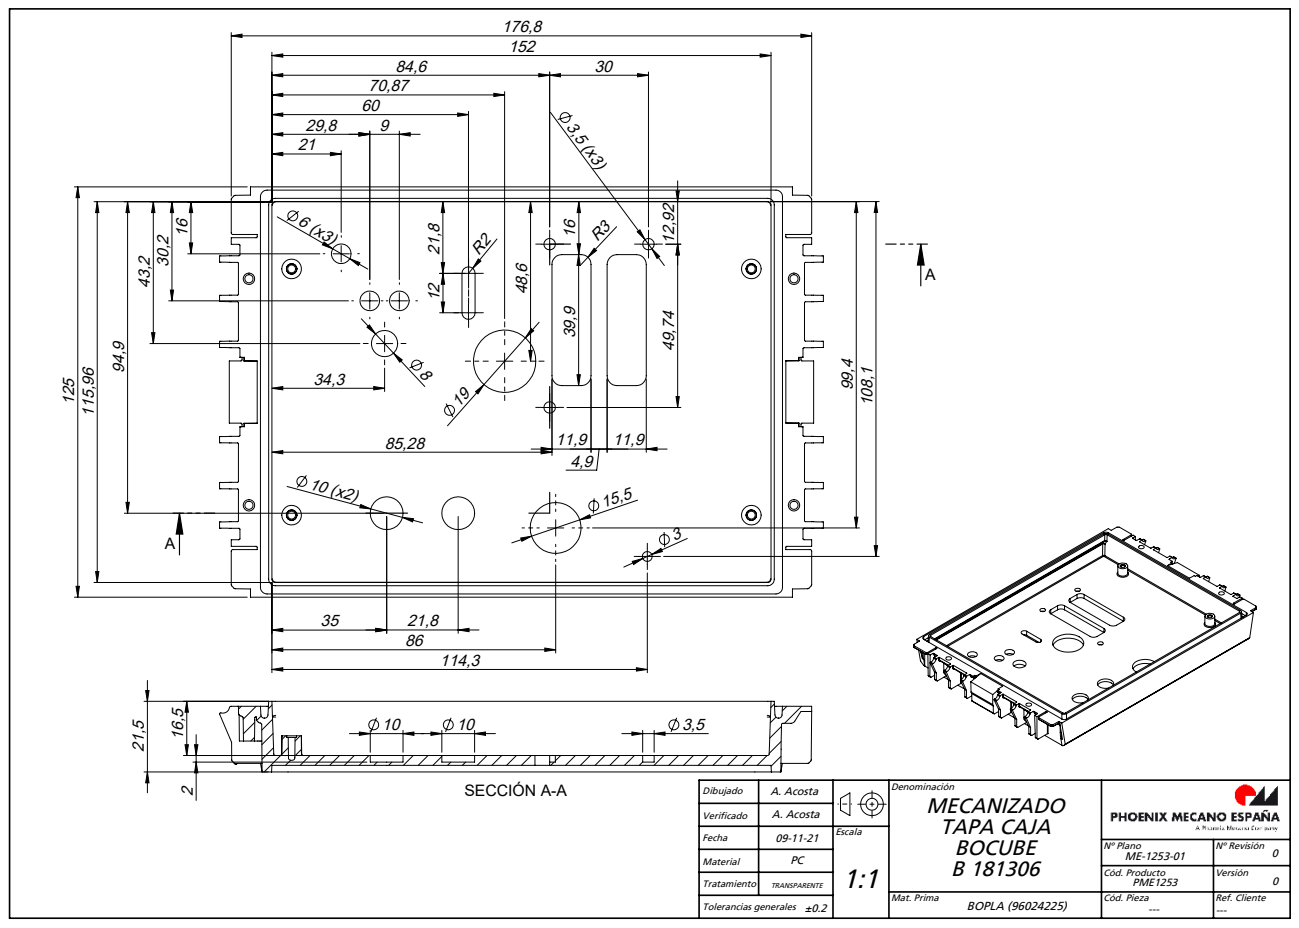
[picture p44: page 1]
SECCIÓN A-A; Tolerancias generales

Dibujado | A. Acosta | | Denominación MECANIZADO TAPA CAJA BOCUBE
Fecha | 09-11-21 | Escala 1:1 | B 181306 PC

Verificado | A. Acosta

Nº Plano ME-1253-01 | Nº Revisión 0

Material

Cód. Producto PME1253 | Versión 0

Tratamiento | TRANSPARENTE

Mat. Prima BOPLA (96024225) | Cód. Pieza --- | Ref. Cliente ---

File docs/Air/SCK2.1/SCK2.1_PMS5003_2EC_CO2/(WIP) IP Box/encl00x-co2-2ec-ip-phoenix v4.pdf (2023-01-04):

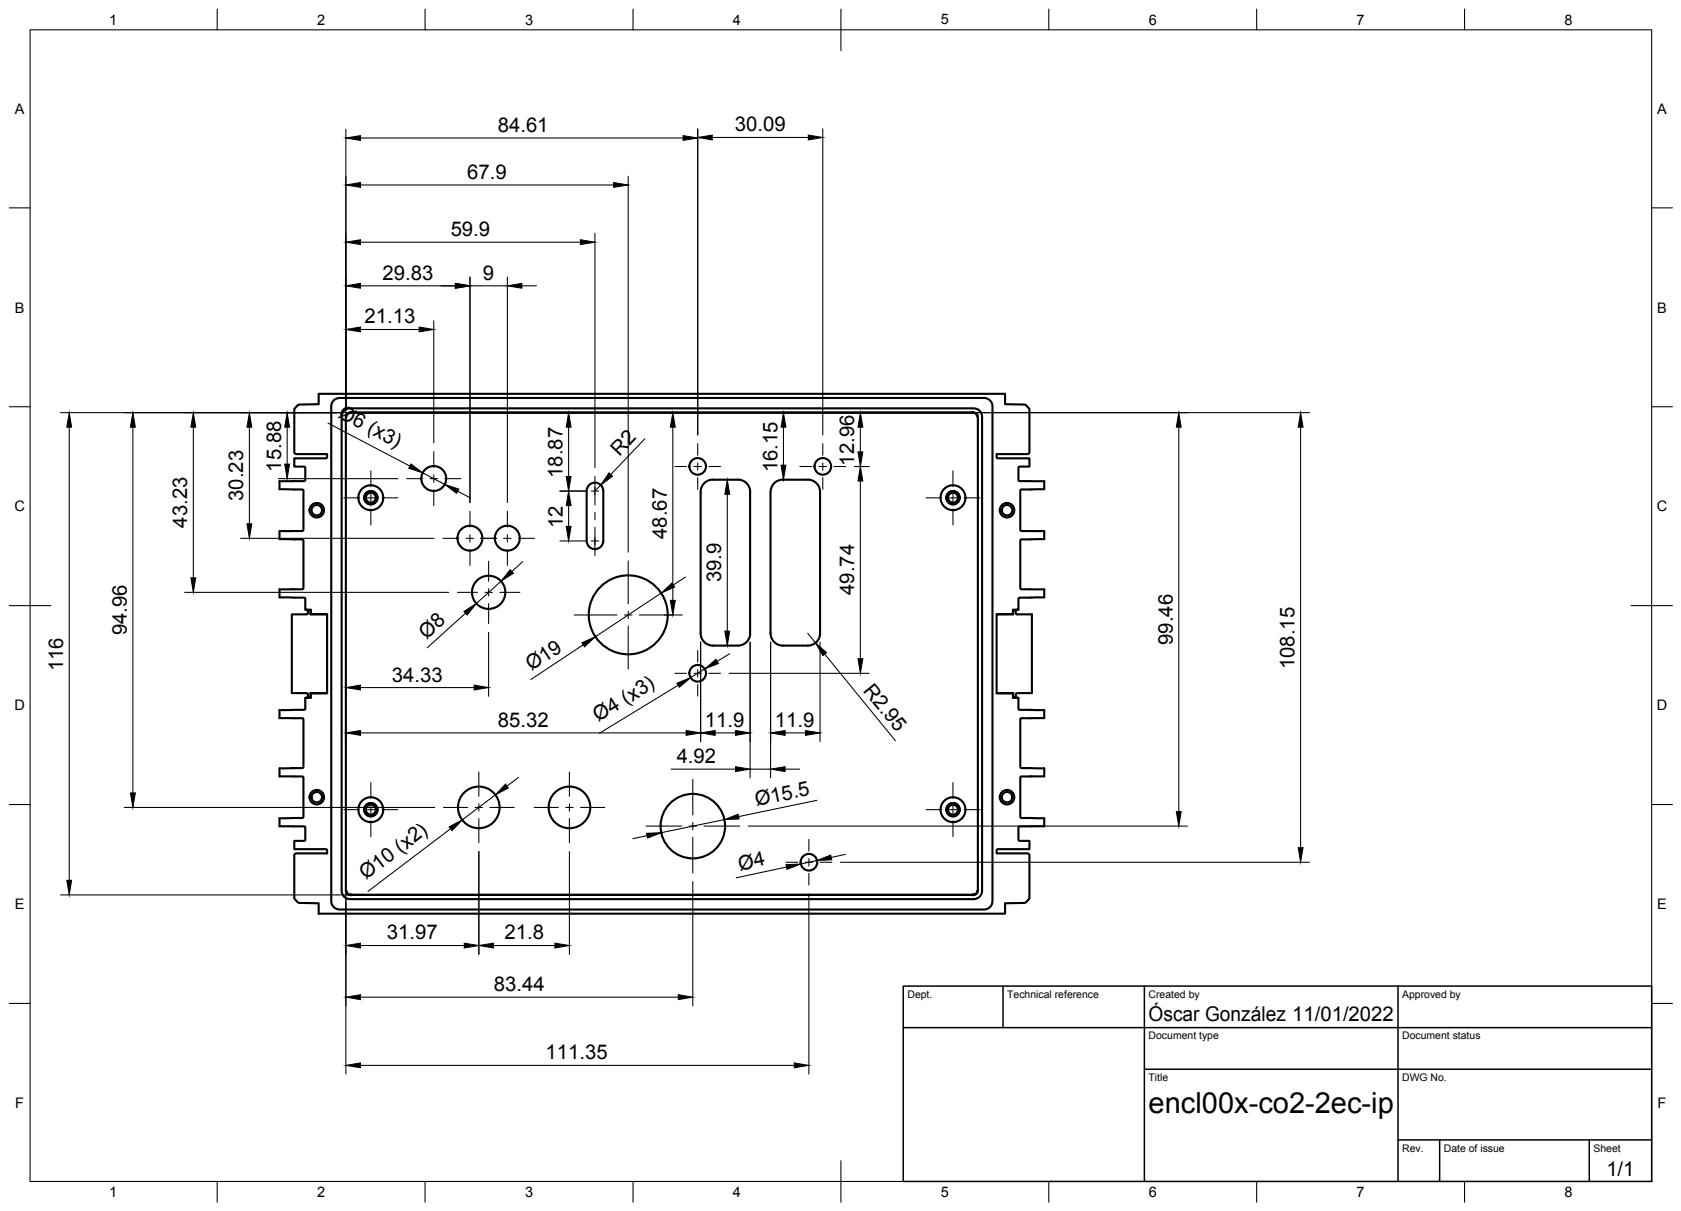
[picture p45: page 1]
Title; DWG No.; Rev.; Date of issue; Sheet; Óscar González 12.96 39.9 11.9 16.15

Dept. | Technical reference | Created by 11/01/2022 | Approved by

Document type | Document status

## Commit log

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2019-09-09 Add outdoor enclosures and components
    [AlphaDELTABoard.stp, BASE.stl, BASE_WO_SUPPORT.stl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]
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2019-11-06 Enclosure STL and image files
    **Traba** is now a bit bigger, as reflected on its STL file.
    [Base.stl, Envolvente.stl, Gland.stl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]
2019-12-20 Update clip and cable gland
    [cap.stl, cap_1.stl, cap_2.stl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]
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2020-04-17 Add iges files for 3d printed and individual components
    [BASE.iges, CABLEGLAND.iges, CLIP.iges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]
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2020-04-27 enlarged cover
    Enlarged cover to fit in a solar MPPT and an additional battery
    [COVER25.STL]
2020-04-27 Add flange for df robot support in bopla
    [FLANGE3mm.dxf, FLANGE3mm.stl]
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2020-09-15 Add Connectivity Uni and update gitignoret
    [BOM.csv]
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2020-11-30 Adding vinyl for AlmaBike
    [folding_vinyl.dxf]
2020-12-01 Smart Citizen Station components
    [alphasense-panel.dxf, clip-3d-support-urban.stl, clip-cable-head.stl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]
2021-01-13 Add Step for 3Dprinted station parts
    [hood-urban.step]
2021-01-21 Add reset and readme
    [holder-reset.stl, sc_reset.kicad_pcb, sc_reset.sch]
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2021-02-23 Add clip foam reduced
    [clip-foam-reduced.stl]
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2021-03-15 Add water station and power option bom
    [PowerSupply.csv, Water Station PATI_BOM.ods, acrylic-1.dxf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]
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2021-03-19 Add 3D printed box
    [base.stl, cover.stl]
2021-03-22 Update 3D printed box
    [base.stl, cover.stl]
2021-03-25 Files for CO2 case and updates on 3D printed box
    [base.stl, cover.stl]
2021-04-06 Update 3D printed version
    [base.stl, cover.stl]
2021-04-12 3D printed CO2 , HDPE and SCK 2.1
    [base.stl, cover.stl]
2021-04-19 Add material for water station
    [Water_Station_BOM.csv]
2021-04-20 CO2 enclosure with acrylic plate
    [acrylic.dxf, base.stl, cover-acrylic.stl]
2021-04-20 Kit 2.1 box version
    [base.stl, cover.stl]
2021-04-20 Minor change in acrylic cover
    [cover-acrylic.stl]
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2021-06-03 Reorganise enclosures repo and add tables
    [3D Print Clips.stl, BASE.iges, BASE.step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]
2021-06-21 Add 2EC version and update readme
    [base.stl]
2021-06-21 Add large umbrella cover for station
    [ALUCOBOND-1019.dxf]
2021-06-21 Rename folder for 2EC CO2
    [base.stl]
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2021-07-06 Add aux002 small cover
    [aux002.dxf, flat_pattern_milling.dxf, spacer.stl]
2021-07-12 Remove some old files in power hub
    [PowerSupply-B.Cu.gbr, PowerSupply-B.Mask.gbr, PowerSupply-B.SilkS.gbr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]
2021-07-12 Add power hub and reset button
    [BOM.csv, power-routing.kicad_pcb, power-routing.sch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]
2021-08-02 Fix bopla on umbrella
    [ALUCOBOND-1019.dxf]
2021-08-02 Reset pcb
    [sc_reset.kicad_pcb, sc_reset.sch]
2021-11-16 Add outdoor cases variants in 3D printing
    [ACRYLIC-TOP.dxf, AFE-CLIP.stl, ASB-BRIDGE.stl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]
2021-11-29 Rename folders to avoid git clone issues
    [3D Print Clips.stl, ACRYLIC-TOP.dxf, AFE-CLIP.stl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]
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2022-01-25 Change reset button and add fabrication files
    [sc_reset.kicad_pcb, sc_reset.sch, sc_reset_small.csv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]
2022-01-25 Add aux cover for rectangle enclosures
    [PLETINA.dxf, aux002.dxf, cover.dxf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]
2022-01-25 Add rectangle enclosures and update readme
    [base.step, base.stl, bridge-asb.step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]
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2022-05-18 Add 3D printed square version - reviewed
    [base.stl, cable-gland.stl, cover.stl]
2022-05-18 Add step and igs files
    [base.iges, base.step, cover.iges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]
2022-05-18 Add step and igs files for improved SCK2.1 model
    [SCK_V2.iges, SCK_V2.step, SCK_V2.stl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]
2022-05-19 3D printed square cover fix
    [cover.iges, cover.step, cover.stl]
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2022-06-22 Fix acrylic for water station
    [acrylic-1.dxf, acrylic-2.dxf]
2022-06-23 Acrylic fix for new button holder
    [acrylic-2.dxf]
2022-06-23 Add holes for reset button
    [acrylic-2.dxf]
2022-07-07 Fixes on acrylic and 3D printed options
    [acrylic-2.dxf, acrylic_bottom.dxf, acrylic_top.dxf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]
2022-07-07 Fix acrylic water station
    [acrylic_top.dxf]
2022-07-07 Acrylic CO2 fix
    [acrylic.dxf]
2022-07-27 Extra 3D printed kit enclosure
    [base_w_holder.stl, cover-acrylic.stl, cover-xl.stl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]
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2022-07-28 Add pm board model
    [sc-pm-board.stl]
2022-07-28 Fix Acrylic box
    [acrylic.dxf]
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2022-09-27 Fix dimension of dibond small cover
    [cover.dxf]
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2022-10-10 Update 3D printed square kit enclosure
    [base.stl, cover.dxf]
2022-10-26 Make holes for covers larger and fix base with holder
    [base.iges, base_w_holder.stl, clip-3d-2000mAh_for_bridge.stl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]
2022-11-16 Add probe holder files
    [adaptor-do-screw.stl, adaptor-do.step, base.step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]
2023-01-04 Global cleanup and reorganising
    [3D Print Clips.stl, 3mm Acrylic Laser Cut.3dm, 3mm Acrylic Laser Cut.dxf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]
2023-01-04 Fix more links and add umbrella for kit
    [cover.dxf]
2023-02-09 Update holder and big station base
    [base.stl, holder-extras-short.stl, holder-sht31.stl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]
2023-02-09 Fix short holder
    [holder-extras-short.stl]
2023-02-16 Add hole for reset
    [plate.dxf]
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2023-05-23 Fix SPS30 enclosures inlet
    [base_sps30_draft.stl]
2023-05-23 Fix clip
    [clip-3d-2000mAh-sps30 v21.stl, clip-3d-2000mAh-sps30.stl]
2023-05-24 Fix clip tolerances
    [clip-3d-2000mAh-sps30.stl]
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2023-06-27 Fix distances on clips
    [base-bottom.stl, base-clip.stl]
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2023-07-11 Add silkscreen to carrier boards
    [i2c_bus_carriers_x5.kicad_pcb, i2c_bus_carriers_x5.kicad_sch]
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2023-07-28 pieces update carrier station
    [Acrylic_top.dxf, Columns_top_acrylic_holder.stl, battery_holder.stl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]
2023-07-28 organize water and add T2
    [Acrylic_bottom.dxf, Acrylic_top.dxf, BOM.csv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]
2023-07-28 Cleanup of old files
    [alphasense-panel.dxf, clip-ziptag.stl, holder-reset.stl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]
2023-07-31 Update parts for station
    [alphasense-3d-plate-small.stl, alphasense-3d-plate.stl, asb-plate.stl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]
2023-07-31 Add spacers and clips
    [clip-foam-reduced.stl, spacer-pm-board.stl, spacer-pm-short.stl]
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2023-09-08 Fixes on cover and add tool
    [lid.stl, tool-cover.stl, top-cover.stl]
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2023-10-09 Re-add Individual EZO Station parts
    [Acrylic_bottom.dxf, Acrylic_top.dxf, CLIP_down_holder.stl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]
2023-10-23 isolated carrier station docu
    [ACRYLIC-BOTTOM.dxf, ACRYLIC-TOP.dxf, CLIP.stl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]
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2023-10-28 Fix base Wip
    [base.iges, base_wip.step, base_wip.stl]
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2024-02-13 fix SCKit forg box sen5x
    [SCKit_base.stl]
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2024-02-22 fix SCK2.2 base indoor
    [base.stl]
2024-02-28 frog box SEN5X new entries CO2 2EC HCHO
    [2EC_support.stl, SCKit_base.stl, SCKit_cover.stl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]
2024-02-29 frog box SEN5X fix CO2+HCHO base
    [base.stl]
2024-02-29 Adding folder structure "assets" and "components" to SCK 2.2
    [2EC_support.stl, SCKit_base.stl, SCKit_cover.stl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]
2024-03-01 frog box SEN5X fix 2EC base
    [base.stl]
2024-03-05 frog box SEN5X fix 2EC/CO2+HCHO base
    [base.stl]
2024-03-14 frog box SEN5X fix 2EC base fix
    [base.stl]
2024-03-14 frog box SEN5X fix 2EC cover fix & add 2EC bridge
    [2EC_brigde.stl, cover+holder.stl]
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2024-03-19 Rename some items and backup of initial version of frogbox SCK2.1
    [base.stl, base_05.stl, clamp_01.stl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]
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2024-03-20 Base for SCK2.2 CO2 + HCHO fixes
    [base.stl, base_fix.stl]
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2024-04-16 Fix cable clip dimensions
    [cable-clip_BNC.stl]
2024-04-19 frogbox 2.1 base fix SCKit
    [base.stl]
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2024-05-03 Improve description of water units, still some todos
    [ACRYLIC-BOTTOM.dxf, ACRYLIC-TOP.dxf, Acrylic_bottom.dxf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]
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2024-05-08 fix water station carriers support
    [Acrylic_bottom.dxf, Acrylic_top.dxf, CLIP_down_holder.stl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]
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2024-09-16 base SCK2.2_SEN5X fix
    [base.stl, base_extTemp_sensor.stl]
2024-09-16 base SCK2.2_SEN5X CO2+HCHO fix
    [base.stl]
2024-09-16 base SCK2.2_SEN5X CO2 fix
    [base.stl]
2024-09-16 base SCK2.2_SEN5X 2EC fix
    [base.stl]
2024-09-16 base SCK2.2_SEN5X HCHO TGS PID fix
    [base.stl]
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2024-09-17 fix base HCHO PID TGS
    [base.3mf, base.stl]
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2025-01-23 fix links
    [clip-sck2.2-sen5x.stl, clip-sck2.X-sen5X.stl]
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2025-03-05 Corrections power supply and umbrella pages
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2025-04-25 2.3 medium enclosures README.md names fix
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2025-10-07 README.md outdoor enclosure fix
2025-12-11 fix 3dPrinted outdoor STLs
    [baseDW.stl, baseUP.stl, batteryBridge.stl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]
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
